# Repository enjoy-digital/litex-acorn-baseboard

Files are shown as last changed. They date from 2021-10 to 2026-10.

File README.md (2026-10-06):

                                  __   _ __      _  __    ___
                                 / /  (_) /____ | |/_/___/ _ |_______  _______
                                / /__/ / __/ -_)>  </___/ __ / __/ _ \/ __/ _ \
                               /____/_/\__/\__/_/|_|__ /_/ |_\__/\___/_/ /_//_/
                                 / _ )___ ____ ___ / /  ___  ___ ________/ /
                                / _  / _ `(_-</ -_) _ \/ _ \/ _ `/ __/ _  /
                               /____/\_,_/___/\__/_.__/\___/\_,_/_/  \_,_/
                                    Copyright 2021-2026 / Enjoy-Digital






[> Intro
--------

The LiteX-Acorn-Baseboards are baseboards developed around the SQRL Acorn card (and the compatible
RHS Research LiteFury/NiteFury), extending their possibilities with additional connectivity and I/Os.
Two variants exist:

**Mini variant** — commercialized, available on our [webshop][webshop]:

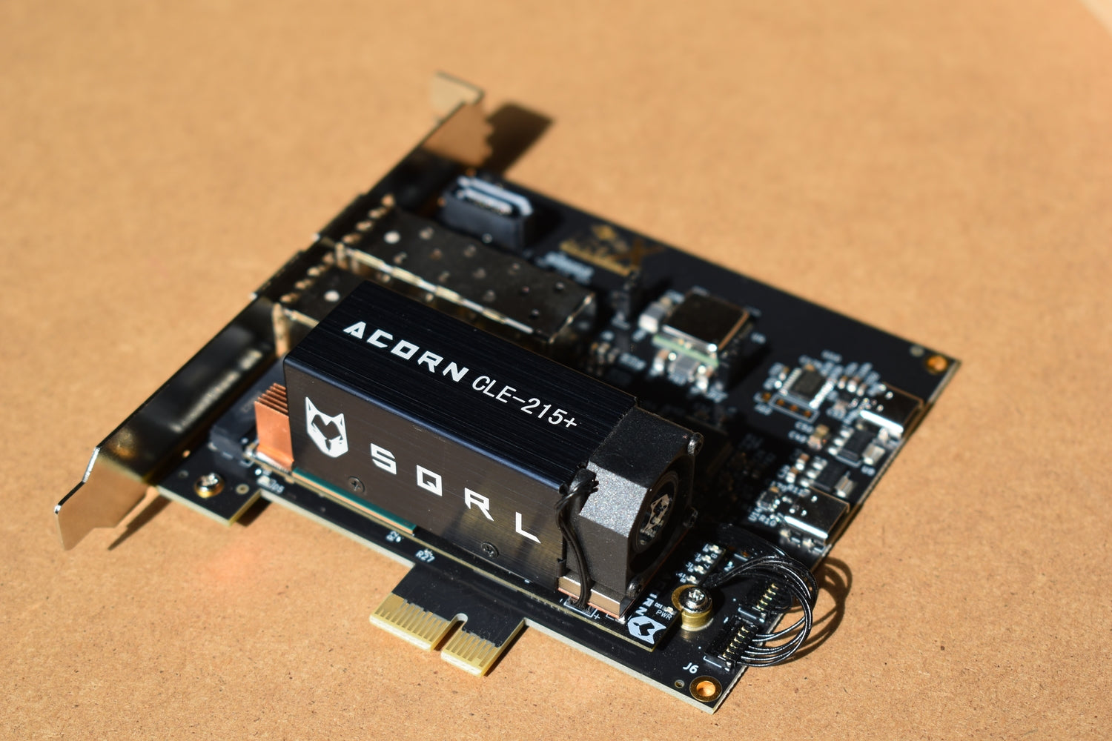
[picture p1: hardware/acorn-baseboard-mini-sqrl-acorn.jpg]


- An M.2 connector for the Acorn/LiteFury/NiteFury (or [LiteX-M2SDR][m2sdr]).
- A PCIe X1 connector.
- 2 SFP connectors.
- A SATA connector.
- 2 PicoEzMate connectors (GPIOs).
- 2 USB-C connectors: one for JTAG/UART (onboard FT2232H or FT4232H depending on the revision, auto-detected by the scripts) and one for power (onboard 3.3V regulator).

**Standard variant** — internal development only, not commercialized:

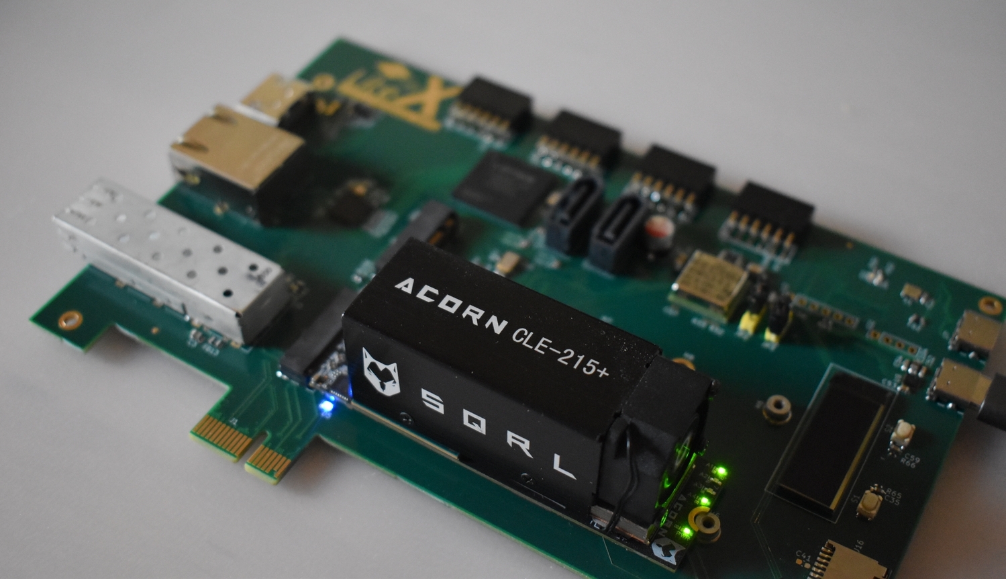
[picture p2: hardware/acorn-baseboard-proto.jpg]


- A PCIe X1 connector.
- An SFP connector.
- An M.2 SATA slot.
- An ECP5 FPGA (connected to the Acorn through a SerDes link) and providing:
  - A JTAG/UART port.
  - A 1Gbps Ethernet port (RGMII).
  - An HDMI Out port.
  - An SDCard slot.
  - 4 PMODs.
  - 2 Buttons.
  - An SSD1306 LCD.
  - 2 SATA connectors (connected to the ECP5's SerDeses).

The boards are primarily intended as development platforms for LiteX — from regression testing to
the development of new features — but they also make nice, affordable FPGA development boards for
anyone wanting to play with PCIe, SFP, SATA, etc., or to build standalone open-source Linux
platforms.

The development was specified and funded by [Enjoy-Digital][enjoy-digital] (@enjoy-digital), who
also did the HDL/gateware development. The schematic/PCB was designed by Ilia Sergachev
(@sergachev), who also assembled the initial prototypes.

[> Availability & Pricing
-------------------------

The **Mini variant** is produced in small batches and available on our webshop:

- Baseboard alone: https://enjoy-digital-shop.myshopify.com/products/litex-acorn-baseboard-mini
- Baseboard + SQRL Acorn CLE215 bundle:
  https://enjoy-digital-shop.myshopify.com/products/litex-acorn-baseboard-mini-sqrl-acorn-cle215

The **Standard variant** is currently used for internal R&D; no decision has been made yet about
producing it commercially.

The aim of the boards is to enable new kinds of designs with LiteX and to make it easier for users
to experiment with the framework and eventually contribute. **We produce and sell them to help
others have fun with LiteX/SerDes-based cores more than to make a living**, so batches are of
limited size and still partly assembled by hand. We try to stay responsive, but **there can be a
delay between batches (~1 month) and a few days between order and shipment**.

[> Getting Started
------------------

### Prerequisites
- Python 3.
- Xilinx Vivado (for the Acorn's Artix-7 FPGA).
- OpenOCD **0.12+** — [`flash.py --unprotect`](flash.py) uses `jtagspi cmd`, which is
  missing in 0.11. Set `OPENOCD=/path/to/openocd` to override the system binary.
- [openFPGALoader](https://github.com/trabucayre/openFPGALoader) — used by `flash.py --flash`.
- JTAG HS2 cable, or any OpenOCD-compatible cable (not needed for SPI-flash loading over PCIe).

### Installing LiteX
```bash
wget https://raw.githubusercontent.com/enjoy-digital/litex/master/litex_setup.py
chmod +x litex_setup.py
sudo ./litex_setup.py init install
```
... or follow the installation instructions from the LiteX Wiki:
https://github.com/enjoy-digital/litex/wiki/Installation

### First-time flashing (fresh Acorn card)
SQRL Acorn cards ship with their SPI flash in a factory-locked state — block-protect bits set
and, on many units, the Configuration Register QUAD bit set (flash stuck in QPI mode). In QPI
mode openFPGALoader's 1-wire SPI-over-JTAG stub can't even read the flash JEDEC ID, and the FPGA
fails to finish startup after loading the stub (`Done=0`). [`flash.py`](flash.py) splits the
job to work around both:
- `--unprotect` drives **OpenOCD** through a BSCAN-SPI proxy using `jtagspi cmd` to issue a
  software reset (0x66 → 0x99), `WRSR SR=0x00` to clear the block-protect bits, and
  `PPB_ERASE` for any non-volatile per-sector locks. CR is left untouched — `--flash` sets
  it below. SR/CR are read back before and after so you can see the state change.
- `--flash` uses **openFPGALoader** to erase + program the flash, then `--enable-quad` to set
  the flash's CR.QUAD bit to 1 — the Acorn boots in Master SPIx4 mode and needs QE=1 to fetch
  its bitstream on power-up. `--enable-quad` is idempotent, so running `--flash` again on an
  already-quad-enabled card is fine.

```bash
./flash.py --unprotect --flash                    # one-shot fresh-card bring-up
./flash.py --flash                                # re-flash default bitstream
./flash.py --flash --bitstream my_design.bin      # re-flash your own bitstream
./flash.py --unprotect                            # just unlock (no programming)
```
The default bitstream in [`prebuilt/`](prebuilt/) is the one we pre-load on boards shipped from the
webshop — a LiteX SoC with PCIe / Ethernet / SATA support, useful as a sanity check that the board
is alive before flashing your own design.

### First build (Mini variant)
A good starting point is the LiteX-Boards target, which covers SoC / DRAM / PCIe / Ethernet / SATA:
```bash
cd litex-boards/litex_boards/targets/
./litex_acorn_baseboard_mini.py --with-pcie --build --load
```
At this stage, if everything works correctly, you should see "LED Phaser" (chaser/wave) animation across LEDs A1 through A4.

See [Designs & Apps](#-designs--apps) below for more involved examples (Linux, PTP, SerDes…).

[> Repository Layout
--------------------

### Schematics — [`hardware/`](hardware/)
- [`acorn-baseboard-mini-2022-06-06.pdf`](hardware/acorn-baseboard-mini-2022-06-06.pdf) — Mini
  variant schematic.
- [`README.md`](hardware/README.md) — Mini variant connectors/jumpers reference (pinouts, power
  and SFP I2C jumpers settings).
- [`acorn-baseboard-mini-top.png`](hardware/acorn-baseboard-mini-top.png) — Mini variant PCB top
  render (connectors/jumpers references).
- [`acorn-baseboard-mini-3d.png`](hardware/acorn-baseboard-mini-3d.png) — Mini variant 3D view.
- [`acorn-baseboard-mini.step`](hardware/acorn-baseboard-mini.step) — Mini variant 3D model (STEP,
  generated from KiCad; U4 RECOM DC/DC and U9 FUSB302 are simplified models).
- [`acorn-baseboard-2021-07-02.pdf`](hardware/acorn-baseboard-2021-07-02.pdf) — Standard variant
  schematic.
- [`acorn.pdf`](hardware/acorn.pdf) — SQRL Acorn card schematic (for reference).

### Bring-up tests — [`bringup/`](bringup/)
Small, self-contained LiteX designs used to validate each sub-system. They are a good source of
minimal examples when you want to reproduce only one feature.

**Mini variant** — [`bringup/mini/`](bringup/mini/):
- [`acorn_litex_soc/`](bringup/mini/acorn_litex_soc/) — Minimal LiteX SoC (BIOS over JTAG-UART).
- [`acorn_pcie/`](bringup/mini/acorn_pcie/) — PCIe Gen2 X1 bring-up.
- [`acorn_serdes/`](bringup/mini/acorn_serdes/) — SerDes PRBS/BER test (PCIe and SFP loopback).
- [`acorn_sfp_eth_1000basex/`](bringup/mini/acorn_sfp_eth_1000basex/) — 1000BASE-X Ethernet over SFP.
- [`acorn_sfp_eth_2500basex/`](bringup/mini/acorn_sfp_eth_2500basex/) — 2500BASE-X Ethernet over SFP.

**Standard variant** — [`bringup/standard/`](bringup/standard/):
- [`acorn_pcie/`](bringup/standard/acorn_pcie/), [`acorn_sata/`](bringup/standard/acorn_sata/),
  [`acorn_sfp_eth_1gbps/`](bringup/standard/acorn_sfp_eth_1gbps/) — Acorn-side peripherals.
- [`acorn_ecp5_link/`](bringup/standard/acorn_ecp5_link/),
  [`acorn_i2c_ecp5/`](bringup/standard/acorn_i2c_ecp5/) — Acorn ↔ ECP5 link and I²C boot control.
- [`ecp5_eth_1gbps/`](bringup/standard/ecp5_eth_1gbps/),
  [`ecp5_hdmi_out/`](bringup/standard/ecp5_hdmi_out/),
  [`ecp5_lcd/`](bringup/standard/ecp5_lcd/),
  [`ecp5_sdcard/`](bringup/standard/ecp5_sdcard/) — ECP5-side peripherals.

[> Designs & Apps
-----------------

The Mini variant is supported across the LiteX ecosystem; good entry points include:

- **LiteX-Boards** — reference SoC target with SoC / DRAM / PCIe / Ethernet / SATA support:
  https://github.com/litex-hub/litex-boards/blob/master/litex_boards/targets/litex_acorn_baseboard_mini.py
- **Linux-on-LiteX-VexRiscv** — run Linux on a VexRiscv SoC (`--board=acorn_baseboard_mini`):
  https://github.com/litex-hub/linux-on-litex-vexriscv
- **LiteX-HW-CI** — Linux regression tests on the board with VexRiscv, NaxRiscv (32/64-bit) or Rocket:
  https://github.com/enjoy-digital/litex_hw_ci/blob/main/configs/test_linux_acorn.py
- **LiteEth** — PTP bench on the board:
  https://github.com/enjoy-digital/liteeth/blob/master/bench/acorn_baseboard_mini_ptp.py
- **LiteICLink** — SerDes PRBS/BER bench on the SQRL Acorn (usable standalone or through the Mini):
  https://github.com/enjoy-digital/liteiclink/blob/master/bench/serdes/sqrl_acorn.py
- **LitePCIe** — PCIe bench on the SQRL Acorn:
  https://github.com/enjoy-digital/litepcie/blob/master/bench/acorn.py
- **LiteSATA** — SATA bench on the SQRL Acorn:
  https://github.com/enjoy-digital/litesata/blob/master/bench/acorn.py

... and more to come. :)

[> Validation Status
--------------------

**Mini variant:**
- [x] PCIe Gen2 X1.
- [x] JTAG.
- [x] UART.
- [x] SFPs.
- [x] SATA.

**Standard variant:**
- [x] PCIe Gen2 X1.
- [x] SFP.
- [x] M.2 SATA SSD.
- [x] ECP5 JTAG/UART.
- [x] Acorn JTAG.
- [ ] Acorn/ECP5 Fast Link.
- [x] Acorn/ECP5 Slow Link (2 of 4 lanes tested).
- [x] ECP5 boot control from Acorn via I²C.
- [x] 1Gbps Ethernet.
- [x] HDMI Out.
- [x] SDCard.
- [x] 4× PMODs.
- [x] 2× Buttons.
- [x] SSD1306 LCD.
- [ ] 2× ECP5 SATA.

[> Contact
----------
E-mail: florent@enjoy-digital.fr

[webshop]: https://enjoy-digital-shop.myshopify.com/
[enjoy-digital]: https://enjoy-digital.fr
[m2sdr]: https://github.com/enjoy-digital/litex_m2sdr

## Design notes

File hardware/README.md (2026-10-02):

[> LiteX-Acorn-Baseboard-Mini: Connectors & Jumpers
---------------------------------------------------

Connectors/jumpers reference for the Mini variant, extracted from the
[schematic](acorn-baseboard-mini-2022-06-06.pdf). See the [top render](acorn-baseboard-mini-top.png)
to locate the references on the PCB (positions below are given with the PCIe edge connector at the
bottom, as in the render).

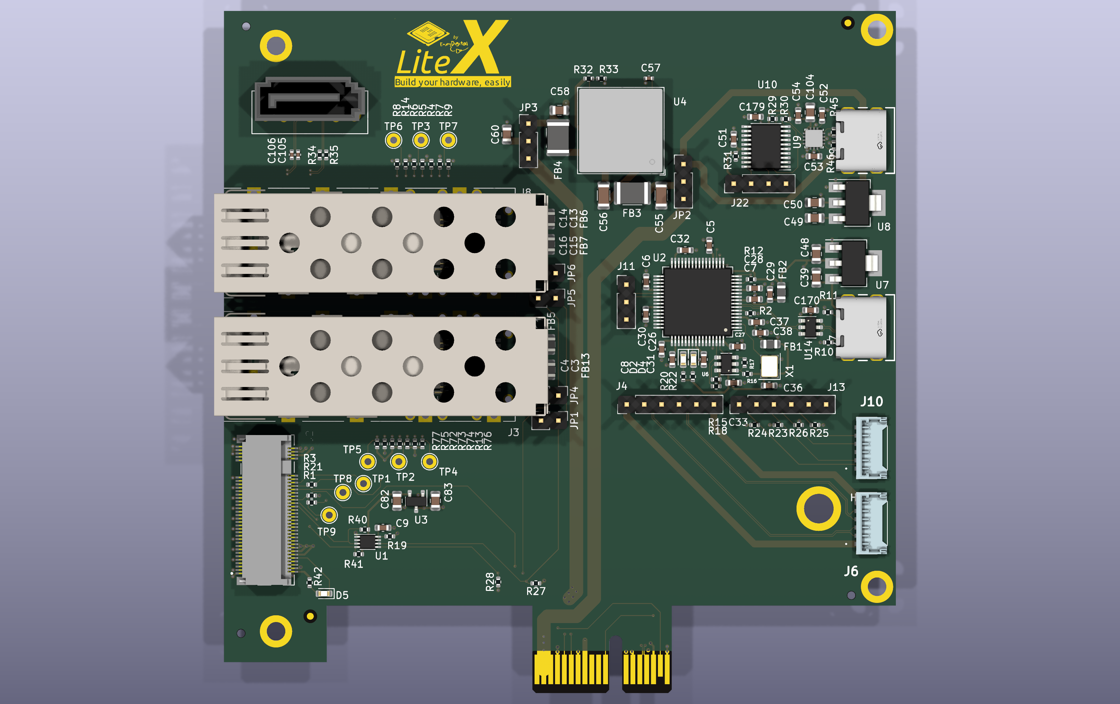
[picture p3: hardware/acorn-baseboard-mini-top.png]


[> Connectors
-------------

| Ref | Description | Notes |
|-----|---|---|
| J1  | PCIe X1 Gen2 card edge. | Also provides +12V/+3.3V power (see JP2/JP3) and SMBus (see JP1/JP4/JP5/JP6). |
| J2  | M.2 key M socket. | For the SQRL Acorn / LiteFury / NiteFury (or LiteX-M2SDR). |
| J3  | SFP0 cage (bottom one, closest to the M.2).  | `sfp0` in the gateware. |
| J8  | SFP1 cage (top one, closest to the SATA). | `sfp1` in the gateware. |
| J5  | SATA connector. | |
| J7  | USB-C (bottom one): JTAG/UART. | Onboard FTDI chip (FT2232H/FT4232H depending on the revision). Also powers the FTDI chip. |
| J9  | USB-C (top one): Power input. | USB Power-Delivery (FUSB302 + STM32 U10). Main power input when not in a PCIe slot. |
| J10 | Pico-EZmate 6-pin: Acorn JTAG. | Connect to the Acorn JTAG connector with a Pico-EZmate 6 cable. |
| J6  | Pico-EZmate 6-pin: Acorn I/O (P2). | Connect to the Acorn P2 connector with a Pico-EZmate 6 cable. |
| J4  | 2.54mm 6-pin header: Acorn I/O breakout. | Same signals as J6 (pin to pin). |
| J13 | 2.54mm 6-pin header: External JTAG. | Shared with the onboard FTDI JTAG and J10, for an external JTAG cable (ex Digilent HS2). |
| J11 | 2.54mm 3-pin header: FTDI UART. | UART also routed to the Acorn through the M.2 connector (no wiring needed). |
| J22 | 2.54mm 4-pin header: STM32 (U10) SWD. | USB-PD controller programming. |

### Pinouts

**J13 — External JTAG** (pin 6 = VDD, compatible with the Digilent HS2 pin order):

| Pin | 1 | 2 | 3 | 4 | 5 | 6 |
|-----|-----|-----|-----|-----|-----|---|
| | TMS | TDI | TDO | TCK | GND | +3V3 |

**J10 — Acorn JTAG (Pico-EZmate)**:

| Pin | 1  | 2 | 3 | 4 | 5 | 6 |
|-----|----|-----|-----|-----|-----|-----|
| | NC | TDI | TMS | TDO | TCK | GND |

**J4/J6 — Acorn I/O (P2)**:

| Pin | 1 | 2 | 3 | 4 | 5 | 6 |
|-----|---|---|---|---|---|---|
| | Acorn P2.1 | AIO1N | AIO1P | AIO2N | AIO2P | Acorn P2.6 |

**J11 — FTDI UART** (FTDI channel B, LiteX `serial` on the Acorn):

| Pin | 1 | 2 | 3 |
|-----|---|---|-----|
| | FTDI TX (-> FPGA RX) | FTDI RX (<- FPGA TX) | GND |

The UART is routed to the Acorn through the M.2 connector (FTDI TX -> M.2 SMB_ALERT#, M.2
CLKREQ# -> FTDI RX) so J11 is only needed to monitor or connect to the UART externally.

**J22 — STM32 SWD**:

| Pin | 1 | 2 | 3 | 4 |
|-----|---|---|---|-----|
| | +3.3VA | SWCLK | SWDIO | GND |

[> Jumpers
----------

| Ref | Function | Setting |
|-----|---|---|
| JP2 | 1st power input selector: DC/DC (U4) input. | 1-2: from USB-C J9 (VBUS). 2-3: from PCIe edge connector (+12V). |
| JP3 | 2nd power input selector: Baseboard +3V3 rail. | 1-2: from onboard 3.3V DC/DC (U4, also powering the M.2/Acorn). 2-3: from PCIe edge connector (+3.3V). |
| JP1 | SFP0 I2C SCL <-> PCIe/M.2 SMBus SCL. | Close to access SFP0 I2C (module EEPROM/DDM). |
| JP4 | SFP0 I2C SDA <-> PCIe/M.2 SMBus SDA. | Close to access SFP0 I2C (module EEPROM/DDM). |
| JP5 | SFP1 I2C SCL <-> PCIe/M.2 SMBus SCL. | Close to access SFP1 I2C (module EEPROM/DDM). |
| JP6 | SFP1 I2C SDA <-> PCIe/M.2 SMBus SDA. | Close to access SFP1 I2C (module EEPROM/DDM). |

Notes:
- The Acorn (M.2) is always powered from the onboard 3.3V DC/DC (U4), so JP2 has to be set in all
  cases: 1-2 when powered from USB-C J9 (standalone), 2-3 to use the PCIe +12V when in a PCIe slot.
- The SFP I2C buses are connected to the PCIe SMBus and, through a PCA9306 level-shifter (U1), to
  the M.2 SMBus (`sfp_i2c` in the gateware). Since SFP modules all use the same I2C addresses
  (0x50/0x51), only close the jumpers of one SFP at a time (JP1+JP4 for SFP0 or JP5+JP6 for SFP1).

[> Known Issues
---------------

**SFP TX_DISABLE pull-downs too weak** ([#22](https://github.com/enjoy-digital/litex-acorn-baseboard/issues/22)):
TX_DISABLE (SFP pin 3) is only pulled down to GND by a 4.7k resistor (R75 for SFP0/J3, R7 for
SFP1/J8). SFF-8431 modules have an internal 4.7k-10k pull-up on TX_DISABLE, so with some modules
(mostly copper modules with an internal PHY) TX_DISABLE sits around 1.65V, between the logic
levels, and the module behaves erratically. Replacing R75/R7 with a 1k resistor (or lower) keeps
TX_DISABLE below 0.8V and fixes it.

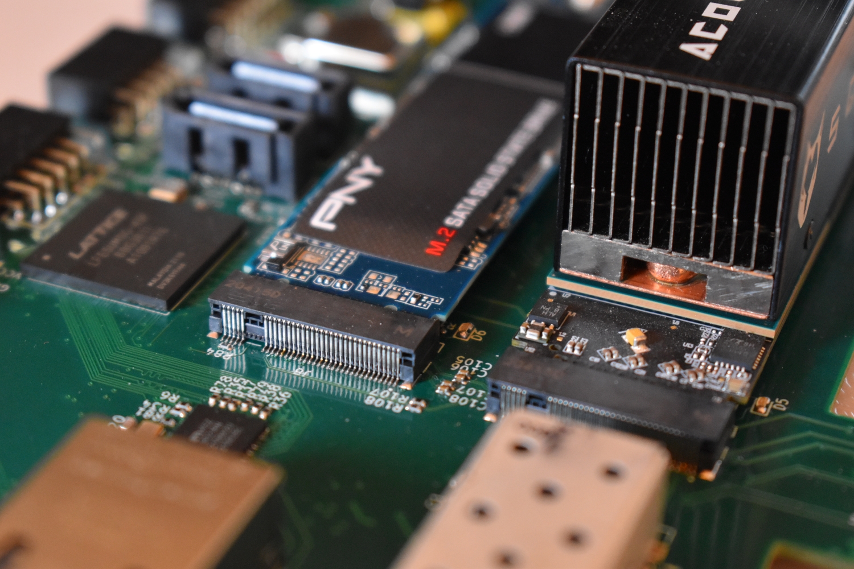
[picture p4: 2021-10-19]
hardware/acorn-baseboard-m2-ssd.jpg

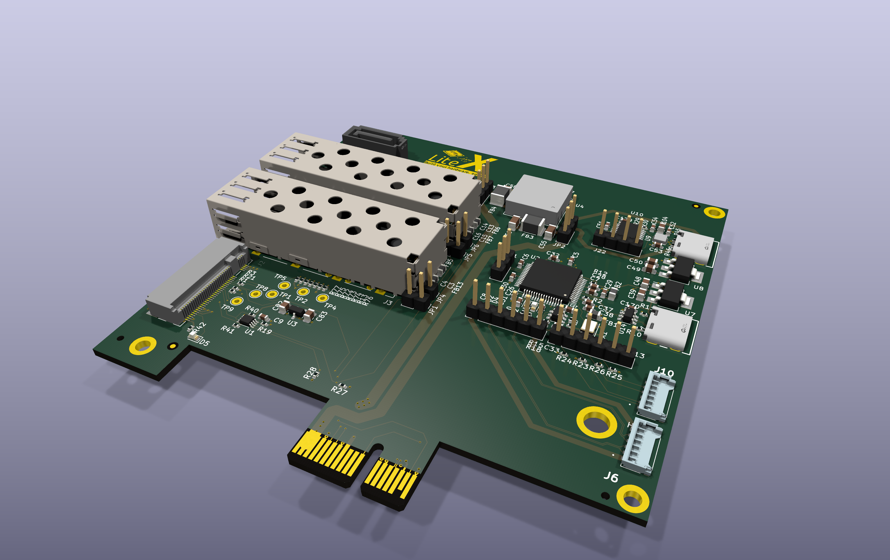
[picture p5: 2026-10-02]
hardware/acorn-baseboard-mini-3d.png

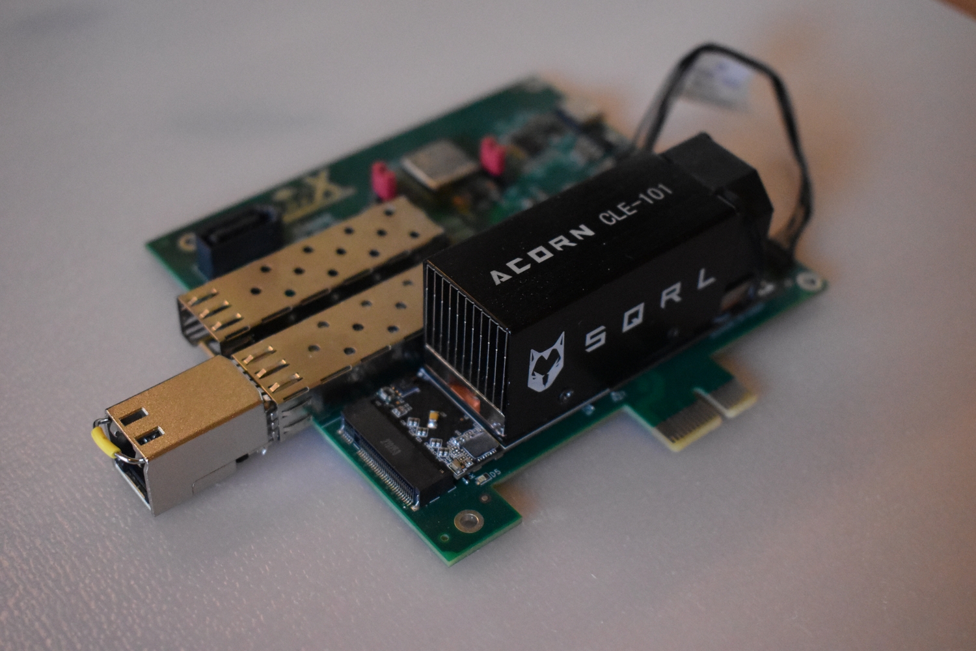
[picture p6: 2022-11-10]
hardware/acorn-baseboard-mini-proto.jpg

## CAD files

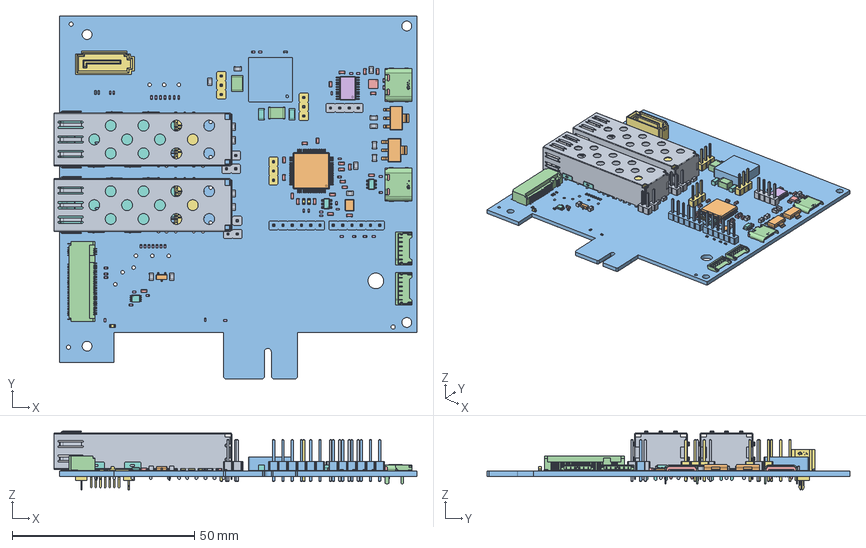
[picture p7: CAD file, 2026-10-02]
hardware/acorn-baseboard-mini.step
99.4 x 99.5 x 16.1 mm
CONN-SMD_APCI0107-P001A
CONN-SMD_20P-P0.80_HCTL_HC-SFP-20P x 2
TH_HC-SFP-01L x 2
LQFP-64_10x10mm_P0.5mm
RECOM_RPM3.3-6.0
C_0603_1608Metric x 26
R_0402_1005Metric x 46
LED_0603_1608Metric x 3
SOT-23-6 x 2
C_0805_2012Metric x 13
SOT-223 x 2
C_0402_1005Metric x 3
L_1812_4532Metric x 2
WQFN-14_2.5x2.5mm
TSSOP-20_4.4x6.5mm_P0.65mm
PinHeader_1x03_P2.54mm_Vertical x 3
C_1206_3216Metric x 2
L_0805_2012Metric x 6
PinHeader_1x04_P2.54mm_Vertical
Crystal_SMD_3225-4Pin_3.2x2.5mm
PinHeader_1x06_P2.54mm_Vertical x 2
USB-C-SMD_TYPEC-304J-BCP16 x 2
CONN-TH_HYC_HYCW01-SATA07-205B
VSSOP-8_2.3x2mm_P0.5mm
PinHeader_1x02_P2.54mm_Vertical x 4
SOT-23
patched_PCB

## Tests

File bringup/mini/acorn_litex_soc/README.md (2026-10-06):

[> Setup
--------
- Power from USB-C (J9).
- USB-C/JTAG connected to Host (J7).
- J10 to Acorn's JTAG connected through PICOEZMATE 6 cable.

[> Build
--------
- ./sqrl_acorn.py --build --load
- litex_term /dev/ttyUSBX (X=2 if only the baseboard connected).

[> Check
--------
LiteX BIOS showing up in litex_term.

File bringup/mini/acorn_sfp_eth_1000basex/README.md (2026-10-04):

[> Setup
--------
- Power from USB-C (J9).
- USB-C/JTAG connected to Host (J7).
- J10 to Acorn's JTAG connected through PICOEZMATE 6 cable.
- SFP 1000-Base-X <-> RJ45 module in SFP0.
- SFP 1000-Base-X <-> RJ45 module in SFP1.

[> Build
--------
./sqrl_acorn.py --build --load

[> Check
--------
- ping 192.168.1.50 responding on SFP0.
- ping 192.168.1.51 responding on SPF1.

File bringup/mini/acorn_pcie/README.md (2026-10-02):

[> Setup
--------
- Power from USB-C (J9).
- USB-C/JTAG connected to Host (J7).
- J10 to Acorn's JTAG connected through PICOEZMATE 6 cable.
- Board in PCIe slot.

[> Build
--------
./sqrl_acorn.py --with-pcie --build --load

Or, to keep the bitstream across power cycles, flash it to the SPI flash:

./sqrl_acorn.py --with-pcie --build --flash

[> Check
--------
Board seen with lspci (Xilinx vendor ID 10ee, device ID 7021 for X1):

lspci -d 10ee:

The first Acorn LED is a LED chaser (bitstream loaded), the second one reflects the PCIe link status.

Note: the host only enumerates PCIe devices at boot, so a bitstream loaded while the host is
running will not appear directly in lspci. The host has to re-enumerate the bus:
- With --load: do a warm reboot of the host. Since the baseboard is powered from its own USB-C
  (J9), the FPGA keeps its configuration across the reboot.
- With --flash: power-cycle the board (or the host) so the FPGA boots from the SPI flash, then
  boot the host.
- A PCIe rescan without reboot (sudo sh -c "echo 1 > /sys/bus/pci/rescan") may also work on some
  hosts, but is not reliable: a reboot is the recommended method.

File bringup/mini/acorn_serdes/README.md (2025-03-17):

[> Setup
--------
- Power from USB-C (J9).
- USB-C/JTAG connected to Host (J7).
- J10 to Acorn's JTAG connected through PICOEZMATE 6 cable.
- PCIe loopback board.
- SFP loopback module.

[> Build
--------
./sqrl_acorn.py --connector=pcie --build --load

[> Check
--------
litex_server --uart --uart-port=/dev/ttyUSBX (X=2 if only the baseboard connected).
./test_prbs.py:
Creating Serdes0
Measuring Serdes0 frequencies...
TX freq:    126.362MHz
RX freq:    126.362MHz
Configuring Serdes0...
Setting PRBS to PRBS7 mode.
Running PRBS/BER test...
Errors:          2 / Duration:  0.50s / BER: 0.000e+00
Errors:          0 / Duration:  1.00s / BER: 0.000e+00
Errors:          0 / Duration:  1.50s / BER: 0.000e+00
Errors:          0 / Duration:  2.00s / BER: 0.000e+00
Errors:          0 / Duration:  2.50s / BER: 0.000e+00
Errors:          0 / Duration:  3.00s / BER: 0.000e+00
Errors:          0 / Duration:  3.50s / BER: 0.000e+00
Errors:          0 / Duration:  4.00s / BER: 0.000e+00
Errors:          0 / Duration:  4.50s / BER: 0.000e+00

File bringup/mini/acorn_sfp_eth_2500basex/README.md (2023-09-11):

[> Setup
--------
- Power from USB-C (J9).
- USB-C/JTAG connected to Host (J7).
- J10 to Acorn's JTAG connected through PICOEZMATE 6 cable.
- SFP 2500-Base-X <-> RJ45 module in SFP0.

[> Build
--------
./sqrl_acorn.py --build --load

[> Check
--------
ping 192.168.1.50 responding.

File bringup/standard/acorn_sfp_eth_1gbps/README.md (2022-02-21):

[> Setup
--------
- Power from USB-C (J9).
- JTAG HS2 to Acorn.
- SFP 1000-BaseX Module (J3).

[> Build
--------
./sqrl_acorn.py --build --load

[> Check
--------
Verify that the board can be pinged at 192.168.1.50.

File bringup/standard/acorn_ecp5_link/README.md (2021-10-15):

[> Setup
--------
- Power from USB-C (J9).
- JTAG HS2 to Acorn.

[> Build
--------
./sqrl_acorn.py --connector=sfp --build --load

[> Check
--------
TODO.

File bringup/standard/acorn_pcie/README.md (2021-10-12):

[> Setup
--------
- Power from USB-C (J9).
- JTAG HS2 to Acorn.
- Board in PCIe slot (J1).

[> Build
--------
./sqrl_acorn.py --with-pcie --build --load

[> Check
--------
Board seen with lspci.

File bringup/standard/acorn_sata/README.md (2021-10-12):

[> Setup
--------
- Power from USB-C (J9).
- JTAG from USB-C (J7).
- JTAG HS2 to Acorn.
- SATA M2 SSD (J8).

[> Build
--------
python3 acorn.py --gen=1 --with-analyzer --build --load
python3 -m litex_boards.targets.litex_acorn_baseboard --cpu-type=None --build --load

[> Check
--------
./test_init.py

    Success (retries: 0)

./test_bist.py -i

    Serial Number: PNY21242106160100189
    Firmware Revision: CS900BB3
    Model Number: PNY CS900 M.2 250GB SSD
    Capacity: 232.89 GiB
    SATA Gen1: 1
    SATA Gen2: 1
    SATA Gen3: 1
    48 bits LBA supported: 1

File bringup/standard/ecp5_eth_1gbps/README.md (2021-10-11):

[> Setup
--------
- Power from USB-C (J9).
- JTAG from USB-C (J7).

[> Build
--------
python3 -m litex_boards.targets.litex_acorn_baseboard --with-etherbone --build --load

[> Check
--------
Verify that the board can be pinged at 192.168.1.50.

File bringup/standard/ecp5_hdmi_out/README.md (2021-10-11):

[> Setup
--------
- Power from USB-C (J9).
- JTAG from USB-C (J7).
- HDMI monitor connected to HDMI Out (J14).

[> Build
--------
python3 -m litex_boards.targets.litex_acorn_baseboard --with-video-terminal --build --load

[> Check
--------
Verify that LiteX BIOS prompt is displayed on the HDMI monitor.

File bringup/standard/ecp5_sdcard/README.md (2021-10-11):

[> Setup
--------
- Power from USB-C (J9).
- JTAG from USB-C (J7).
- SDCard.

[> Build
--------
python3 -m litex_boards.targets.litex_acorn_baseboard --integrated-main-ram-size=0x1000 --with-sdcard --build --load

[> Check
--------

litex_term /dev/ttyUSBX

Without SDCard in slot:

    litex> sdcard_init
    Initialize SDCard... Failed.

With SDCard in slot:

    litex> sdcard_init
    Initialize SDCard... Successful.

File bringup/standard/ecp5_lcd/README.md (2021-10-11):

[> Setup
--------
- Power from USB-C (J9).
- JTAG from USB-C (J7).

[> Build
--------
python3 -m litex_boards.targets.litex_acorn_baseboard --integrated-main-ram-size=0x2000 --with-lcd --build --load

[> Check
--------

litex_term /dev/ttyUSBX

    litex> i2c_scan
           0  1  2  3  4  5  6  7  8  9  a  b  c  d  e  f
    0x00: -- -- -- -- -- -- -- -- -- -- -- -- -- -- -- --
    0x10: -- -- -- -- -- -- -- -- -- -- -- -- -- -- -- --
    0x20: -- -- -- -- -- -- -- -- -- -- -- -- -- -- -- --
    0x30: -- -- -- -- -- -- -- -- -- -- -- -- 3c -- -- --
    0x40: -- -- -- -- -- -- -- -- -- -- -- -- -- -- -- --
    0x50: -- -- -- -- -- -- -- -- -- -- -- -- -- -- -- --
    0x60: -- -- -- -- -- -- -- -- -- -- -- -- -- -- -- --
    0x70: -- -- -- -- -- -- -- -- -- -- -- -- -- -- -- --

cd firmware && make
litex_term /dev/ttyUSBX --kernel=firmware.bin
lcd

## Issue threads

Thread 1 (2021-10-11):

Bringup: Validate Acorn / PCIe.

enjoy-digital, 2021-10-11:
Should work with:

`python3 -m litex_boards.targets.sqrl_acorn --with-pcie --build --load`

With link-width automatically reduced from X4 to X1.

enjoy-digital, 2024-04-19:
This has been validated on both Mini and Standard variants. Standard variants requires a TX/RX pairs swaps due to a schematic/hardware issue. Mini variant has this correction.

Closed 2024-04-19.

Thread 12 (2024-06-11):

Jumpers/connectors documentation and settings table

ohault, 2024-06-11:
Some documentation would be required for LiteX Acorn baseboard, both on PCB and on a wiki page.

Here is a first dump from the schematic.

**Mini variant**

Connectors
J4 : Acorn Pico-EZmate IO
J5 : SATA
J7 : USB Type C
J10 : Acorn JTAG
J11 : Conn_01x03 FT2232 RX/TX
J13 : JTAG header
J22 : STM32 SWD programming

Jumpers
JP2 : 1st power input selector
1-2 from USB-C
2-3 from PCIe edge connector

JP3: 2nd power input selector
1-2 from onboard 3V3 regulator
2-3 from PCIe edge connector

JP1 : SFP0_SCL
JP4 : SFP0_SDA

JP5 : SFP1_SCL
JP6 : SFP1_SDA

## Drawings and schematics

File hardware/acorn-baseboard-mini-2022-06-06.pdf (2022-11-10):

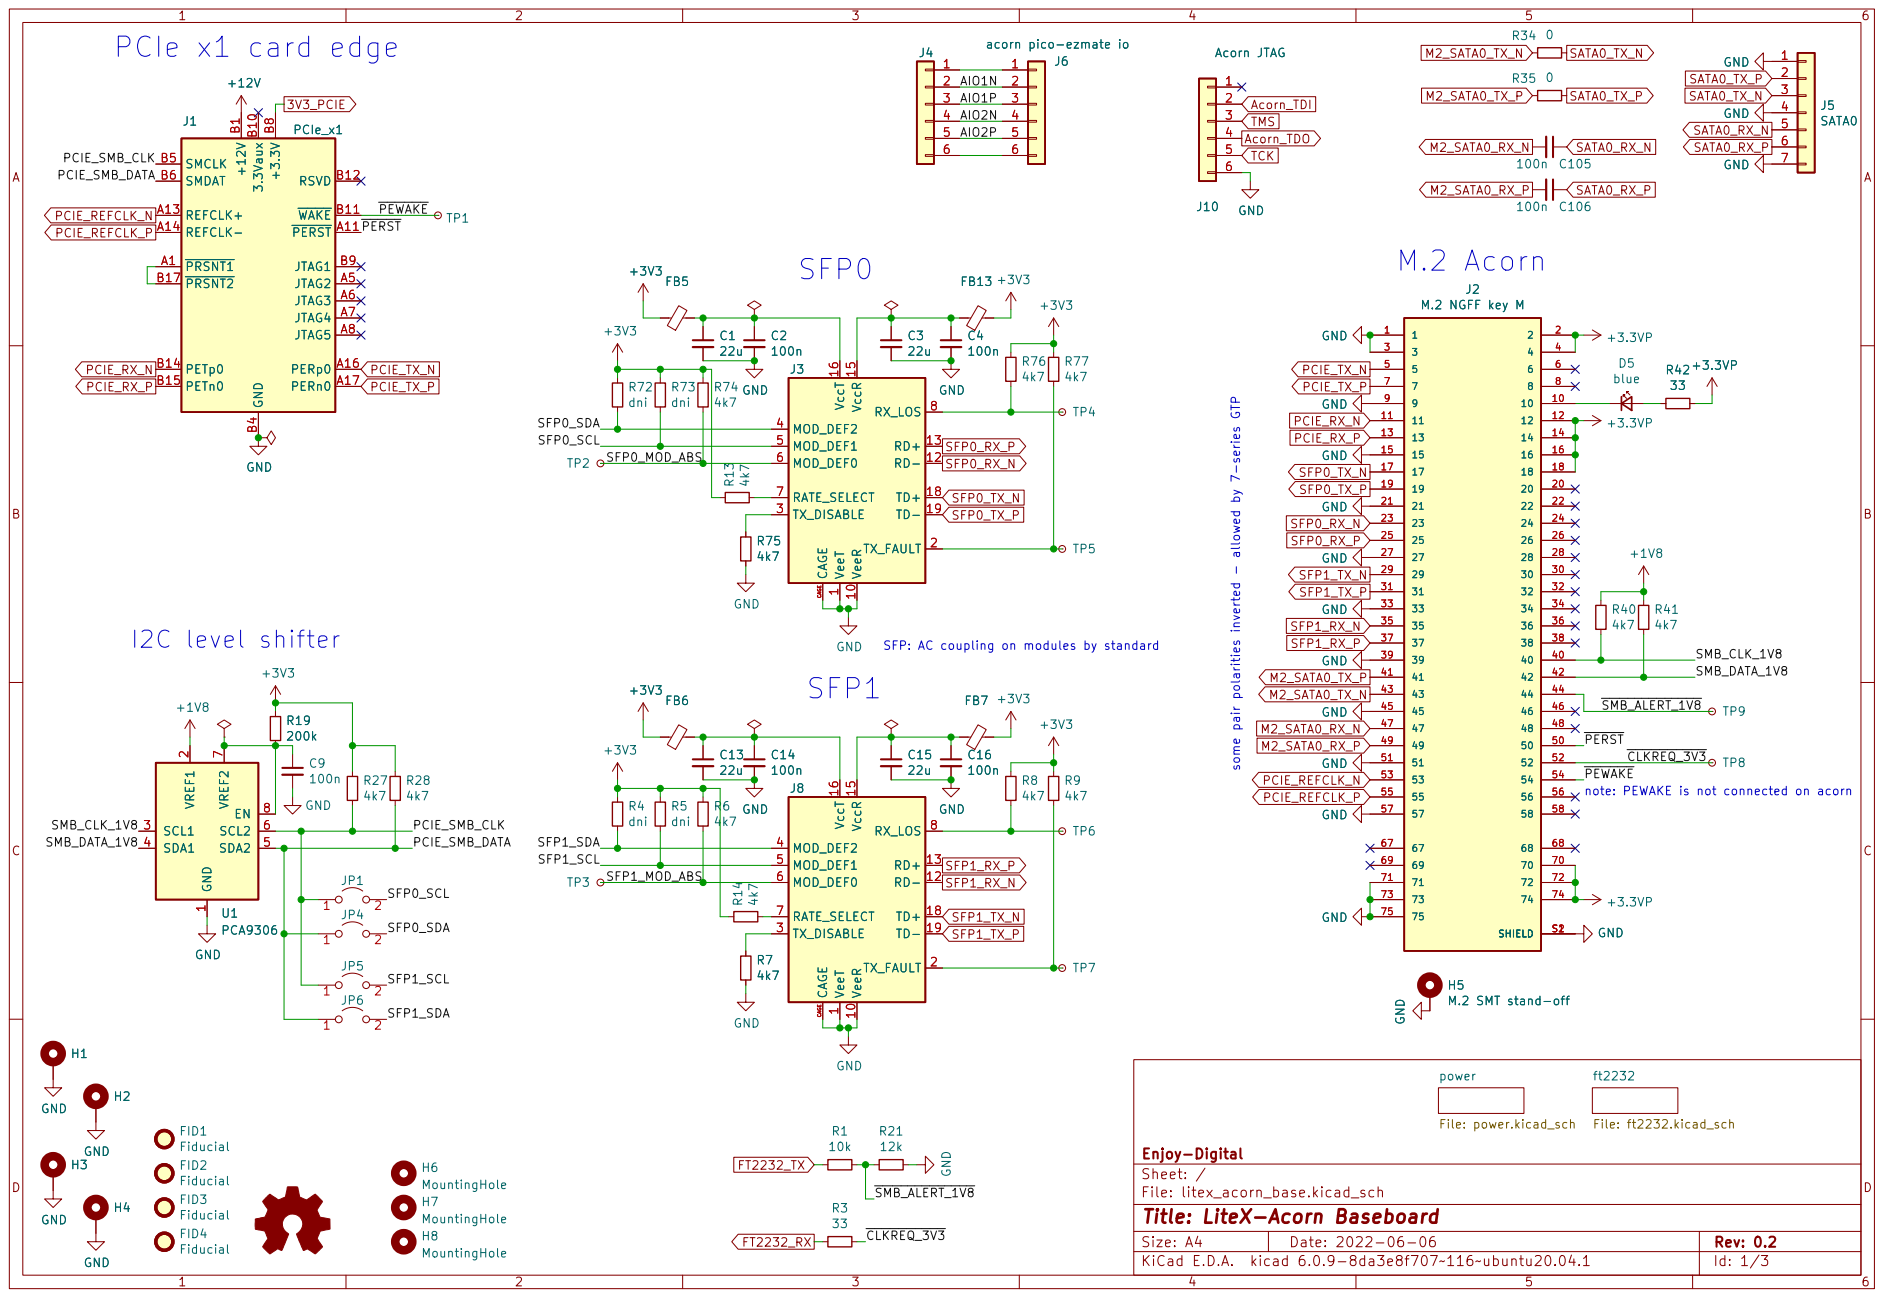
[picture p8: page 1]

acorn pico-ezmate io R9
J10Acorn JTAG

acorn pico-ezmate io

7 GND GND GND GND

note: PEWAKE is not connected on acorn M.2 Acorn

1 VeeR 10 RD- 12 RD+ 13 VccR 15 VccT 16 TD+ 18 TD- 19 TX_FAULT 2 TX_DISABLE 3 MOD_DEF2 4 MOD_DEF1 5 MOD_DEF0 6 RATE_SELECT 7 RX_LOS 8 CAGE CAGE J8 C2

1 VeeR 10 RD- 12 RD+ 13 VccR 15 VccT 16 TD+ 18 TD- 19 TX_FAULT 2 TX_DISABLE 3 MOD_DEF2 4 MOD_DEF1 5 MOD_DEF0 6 RATE_SELECT 7 RX_LOS 8 CAGE CAGE J3 GND GND GND
GND

1 VeeR 10 RD- 12 RD+ 13 VccR 15 VccT 16 TD+ 18 TD- 19 TX_FAULT 2 TX_DISABLE 3 MOD_DEF2 4 MOD_DEF1 5 MOD_DEF0 6 RATE_SELECT 7 RX_LOS 8 CAGE CAGE GND

power File: power.kicad_sch GND GND

1 VeeR 10 RD- 12 RD+ 13 VccR 15 VccT 16 TD+ 18 TD- 19 TX_FAULT 2 TX_DISABLE 3 MOD_DEF2 4 MOD_DEF1 5 MOD_DEF0 6 RATE_SELECT 7 RX_LOS 8 CAGE CAGE R7

H8MountingHole FID1 Fiducial FID3 Fiducial FID4 Fiducial FID2 Fiducial

File: litex_acorn_base.kicad_sch Sheet: / Enjoy-Digital

Id: 1/3 Title: LiteX-Acorn Baseboard

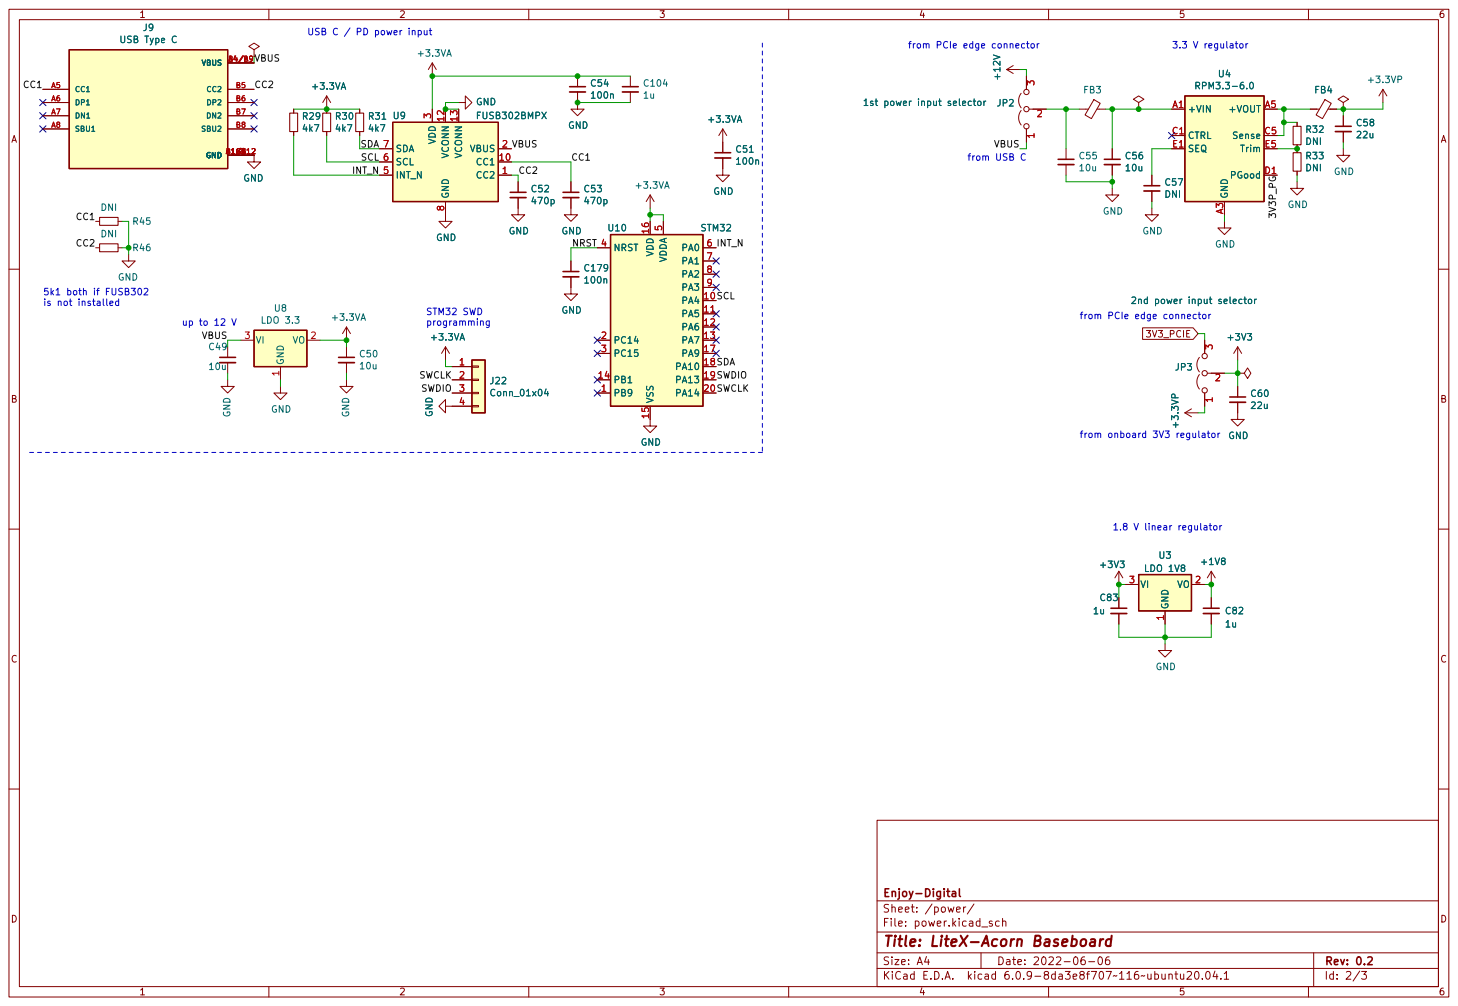
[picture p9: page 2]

USB C / PD power input

from PCIe edge connector

2nd power input selector +3V3 GND

Enjoy-Digital
Sheet: /power/
File: power.kicad_sch
Id: 2/3 Title: LiteX-Acorn Baseboard

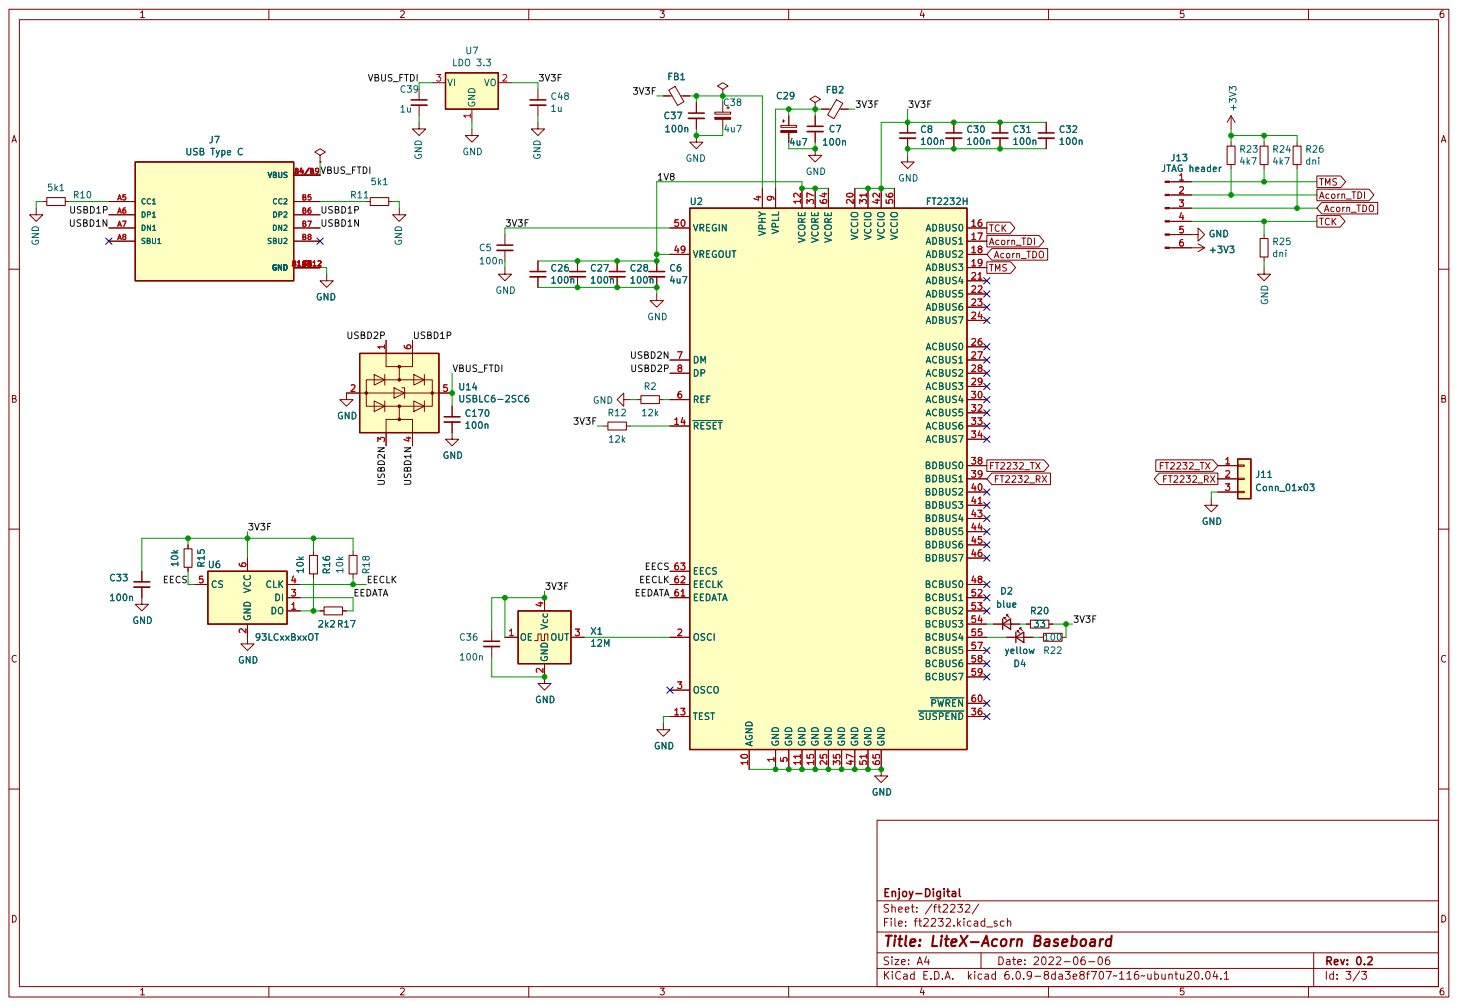
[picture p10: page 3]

1 AGND 10 GND 11 VCORE 12 TEST 13 ~{RESET} 14 GND 15 ADBUS0 16 ADBUS1 17 ADBUS2 18 ADBUS3 19 OSCI 2 VCCIO 20 ADBUS4 21 ADBUS5 22 ADBUS6 23 ADBUS7 24 GND 25 ACBUS0 26 ACBUS1 27 ACBUS2 28 ACBUS3 29 OSCO 3 ACBUS4 30 VCCIO 31 ACBUS5 32 ACBUS6 33 ACBUS7 34 GND 35

4 BDBUS2 40 BDBUS3 41 VCCIO 42 BDBUS4 43 BDBUS5 44 BDBUS6 45 BDBUS7 46 GND 47 BCBUS0 48 VREGOUT 49 GND

5 VREGIN 50 GND 51 BCBUS1 52 BCBUS2 53 BCBUS3 54 BCBUS4 55 VCCIO 56 BCBUS5 57 BCBUS6 58 BCBUS7 59 REF 6 ~{PWREN} 60 EEDATA 61 EECLK 62 EECS 63 VCORE 64 GND 65 DM 7 DP 8 VPLL

2 DI 3 CLK 4 CS 5 VCC

File: ft2232.kicad_sch Sheet: /ft2232/ Enjoy-Digital

Id: 3/3 Title: LiteX-Acorn Baseboard

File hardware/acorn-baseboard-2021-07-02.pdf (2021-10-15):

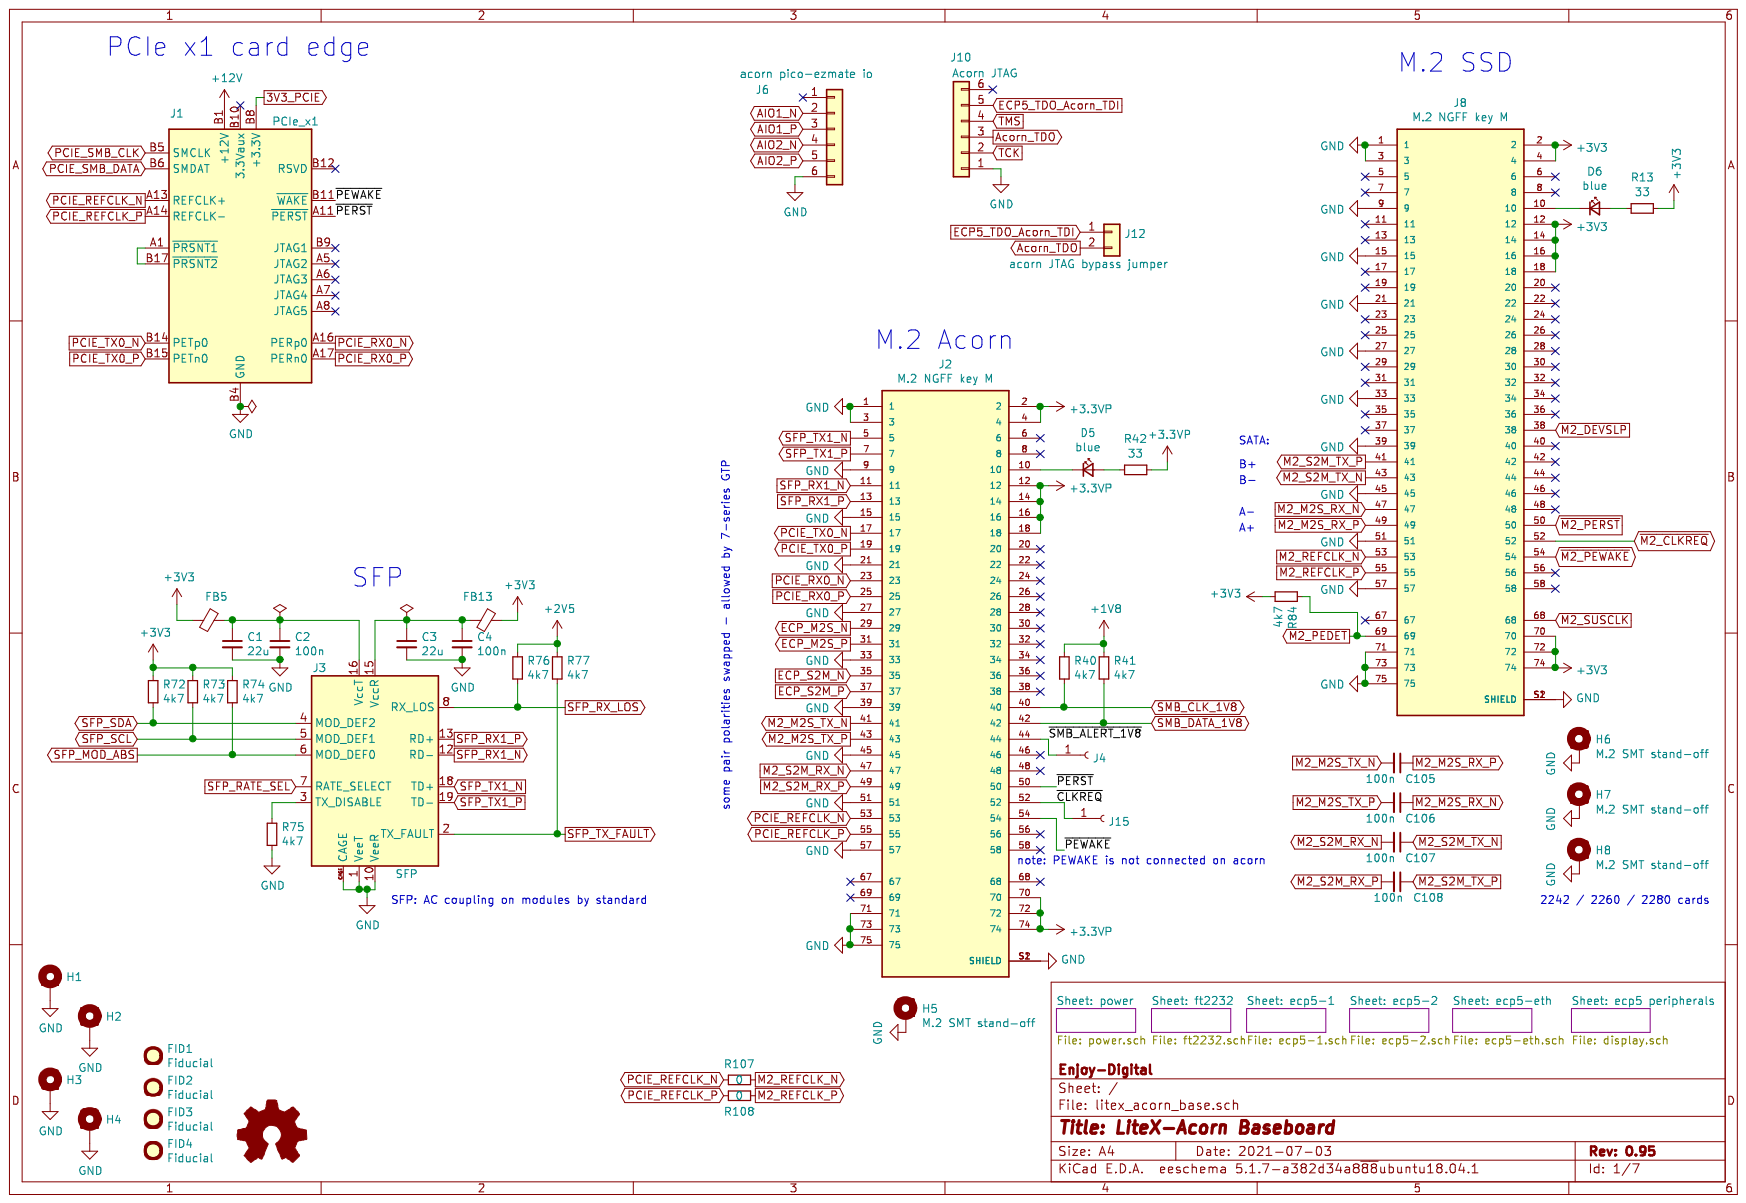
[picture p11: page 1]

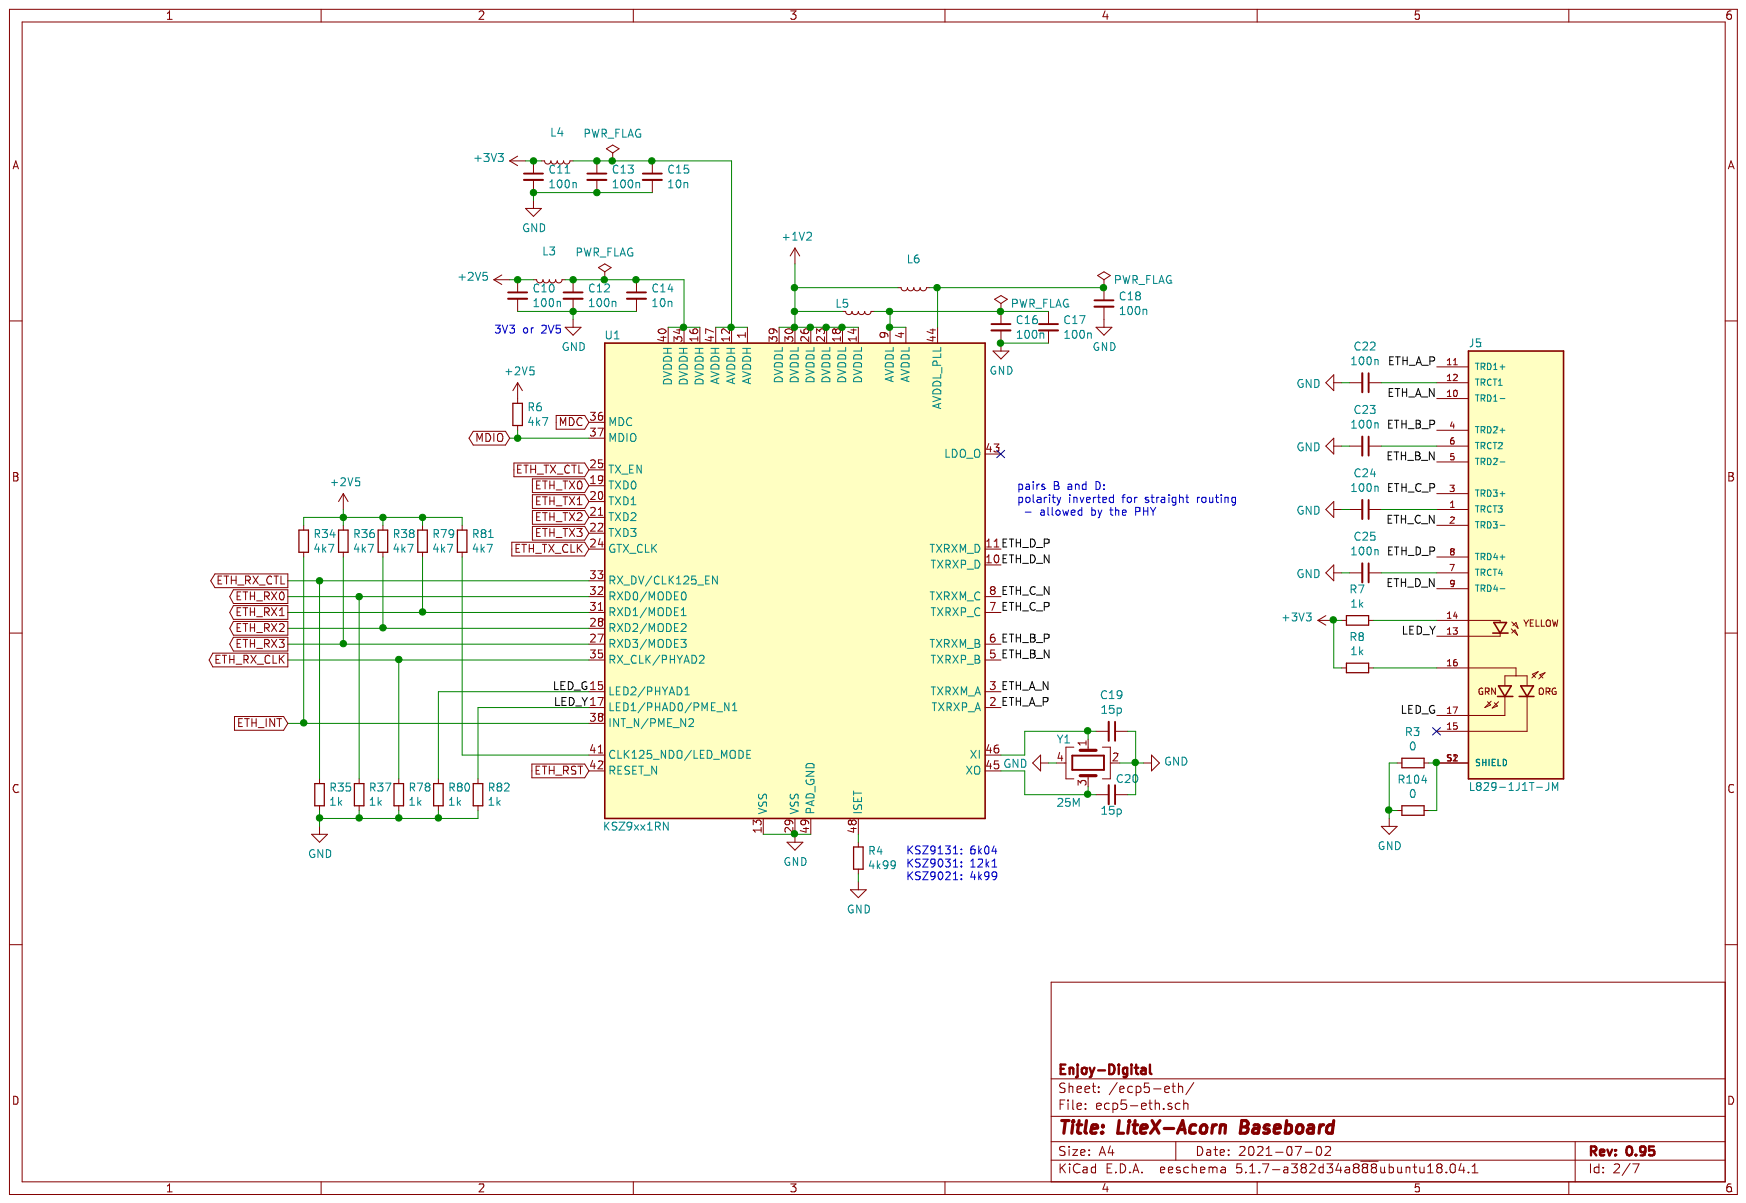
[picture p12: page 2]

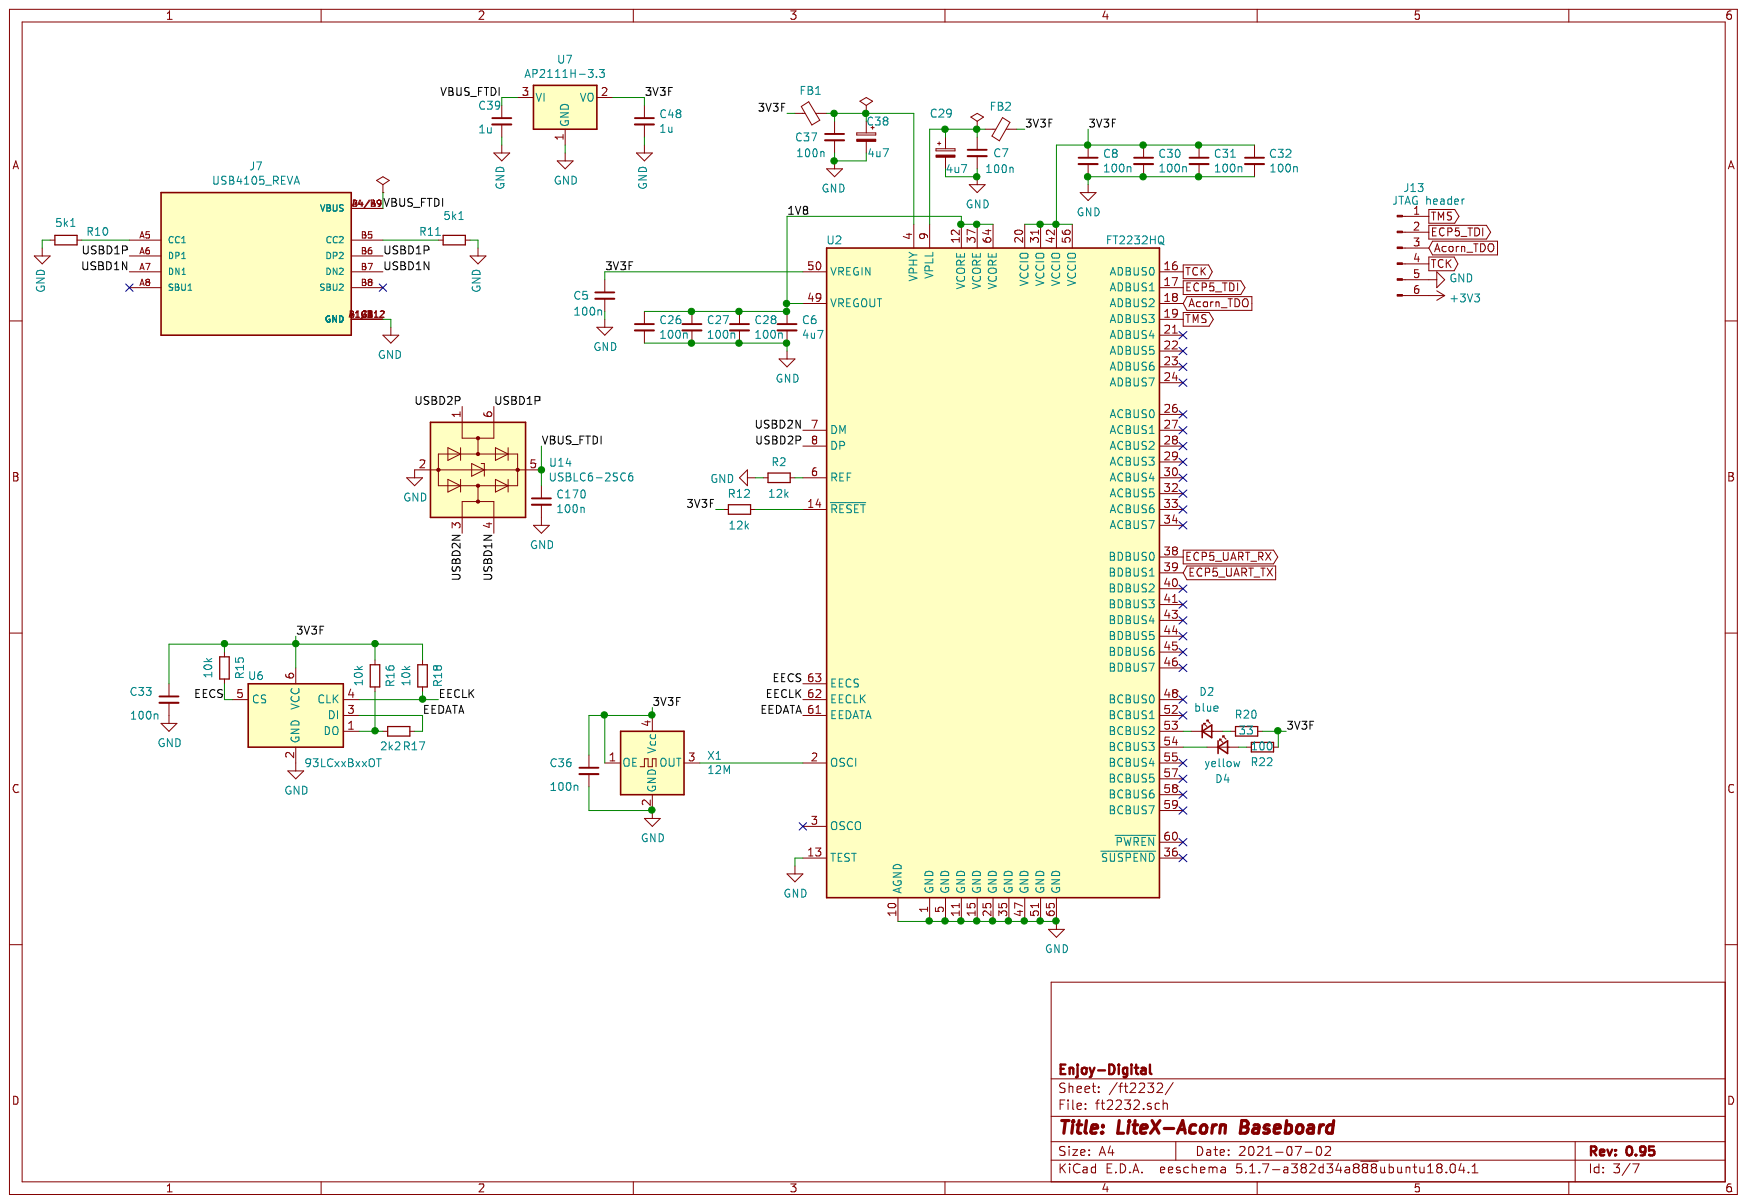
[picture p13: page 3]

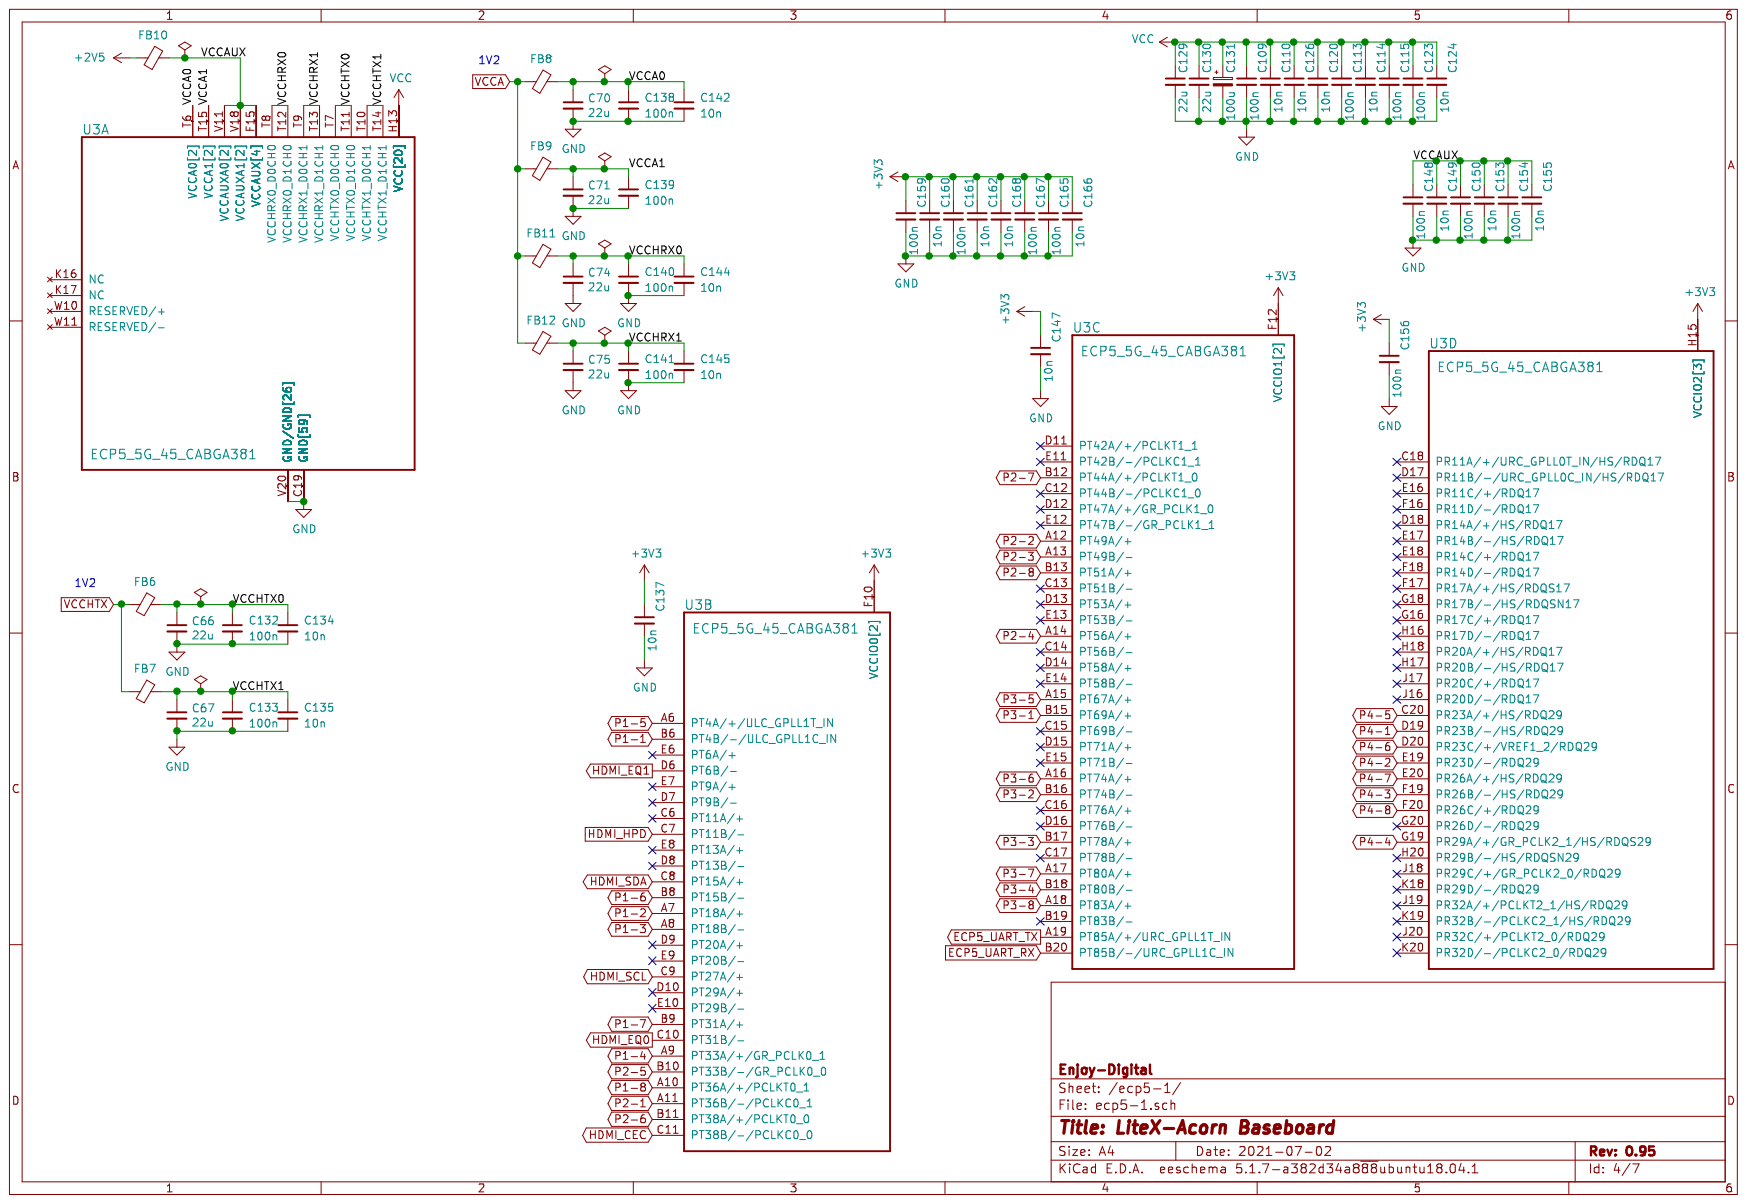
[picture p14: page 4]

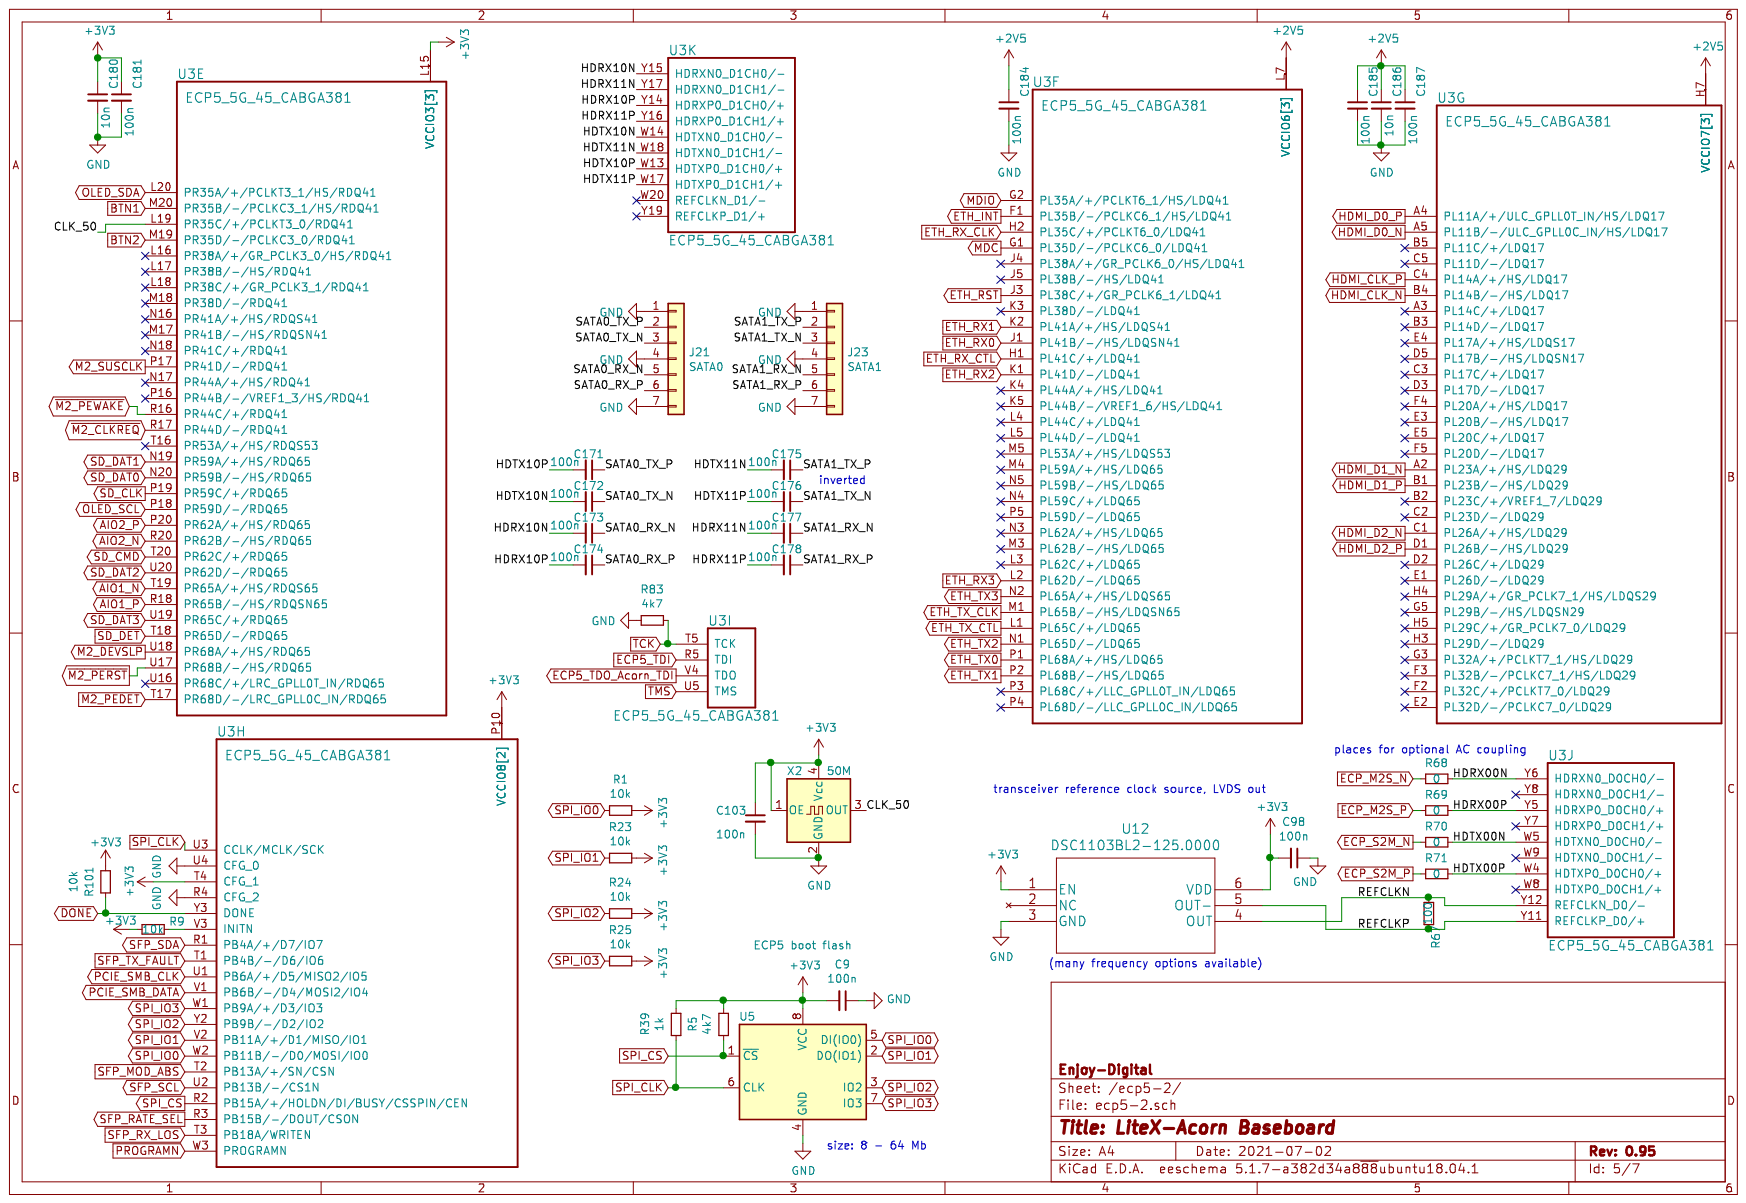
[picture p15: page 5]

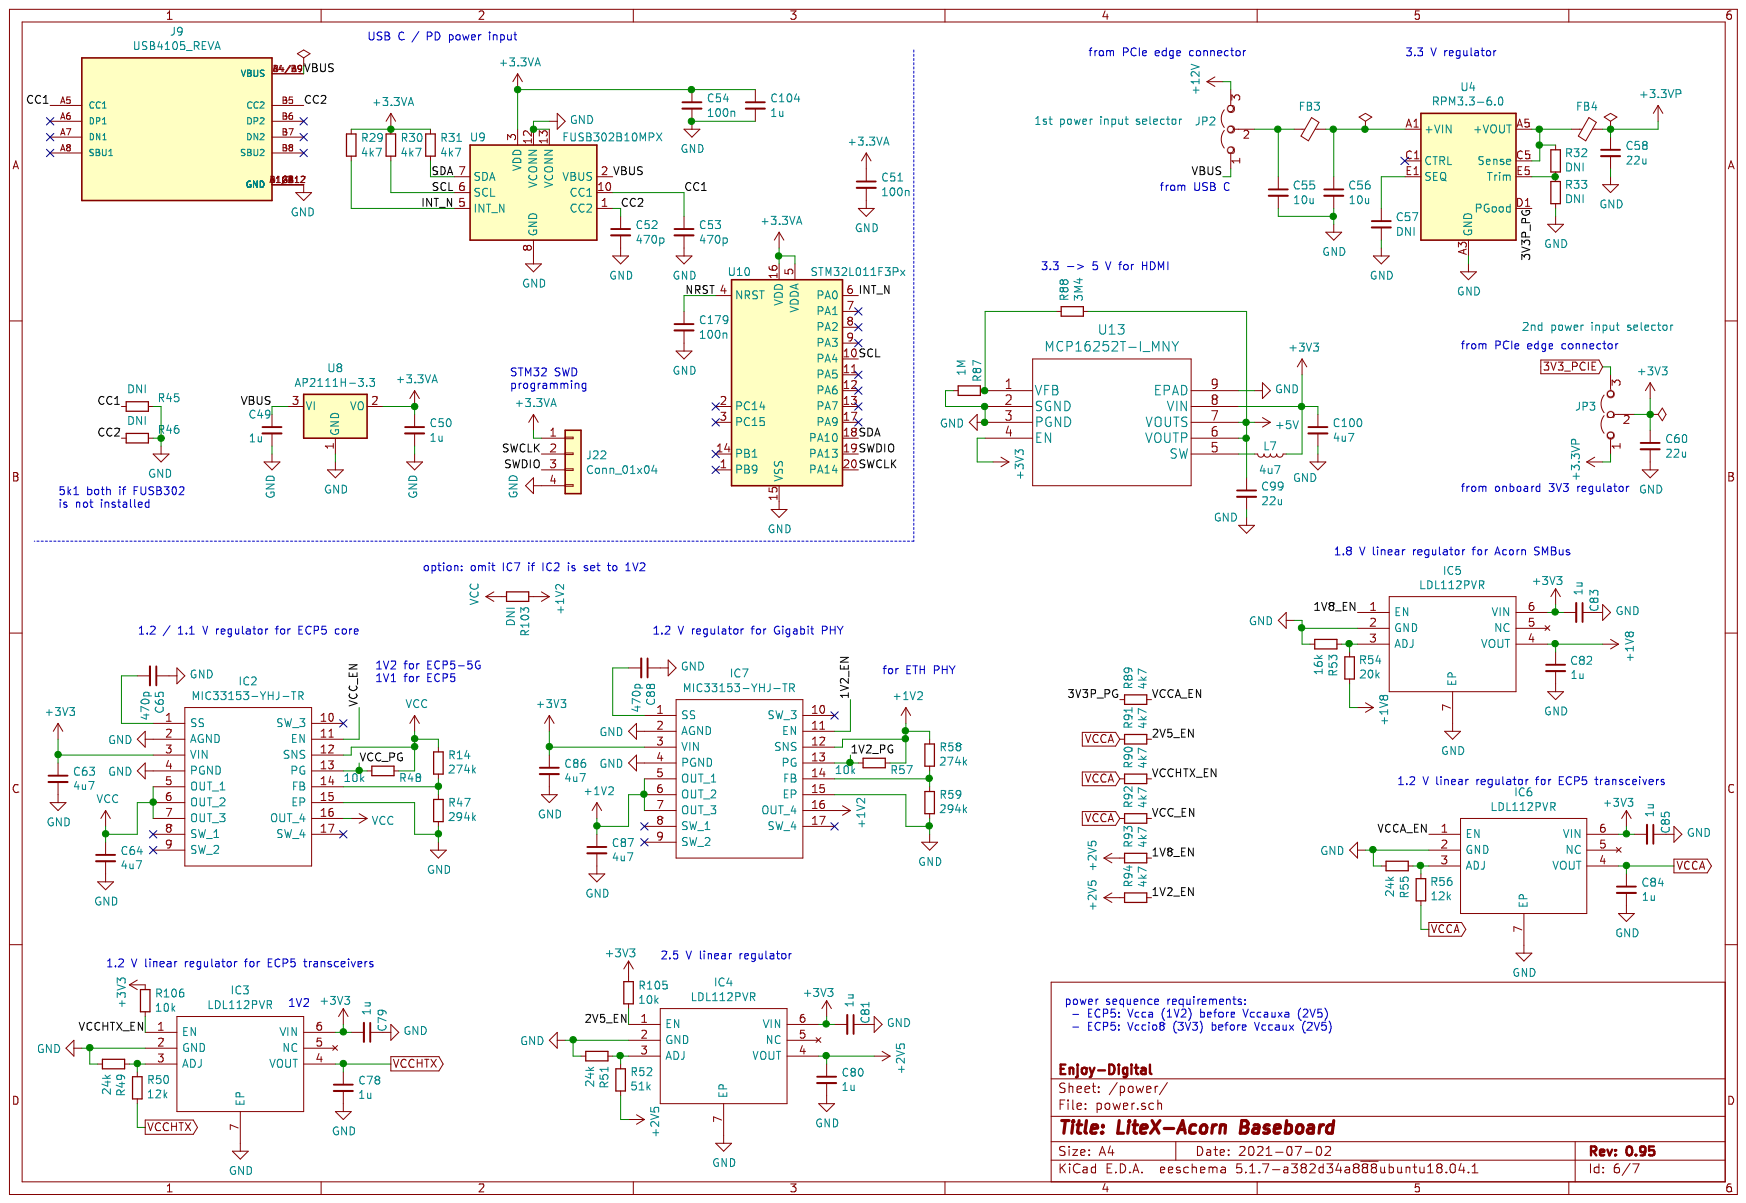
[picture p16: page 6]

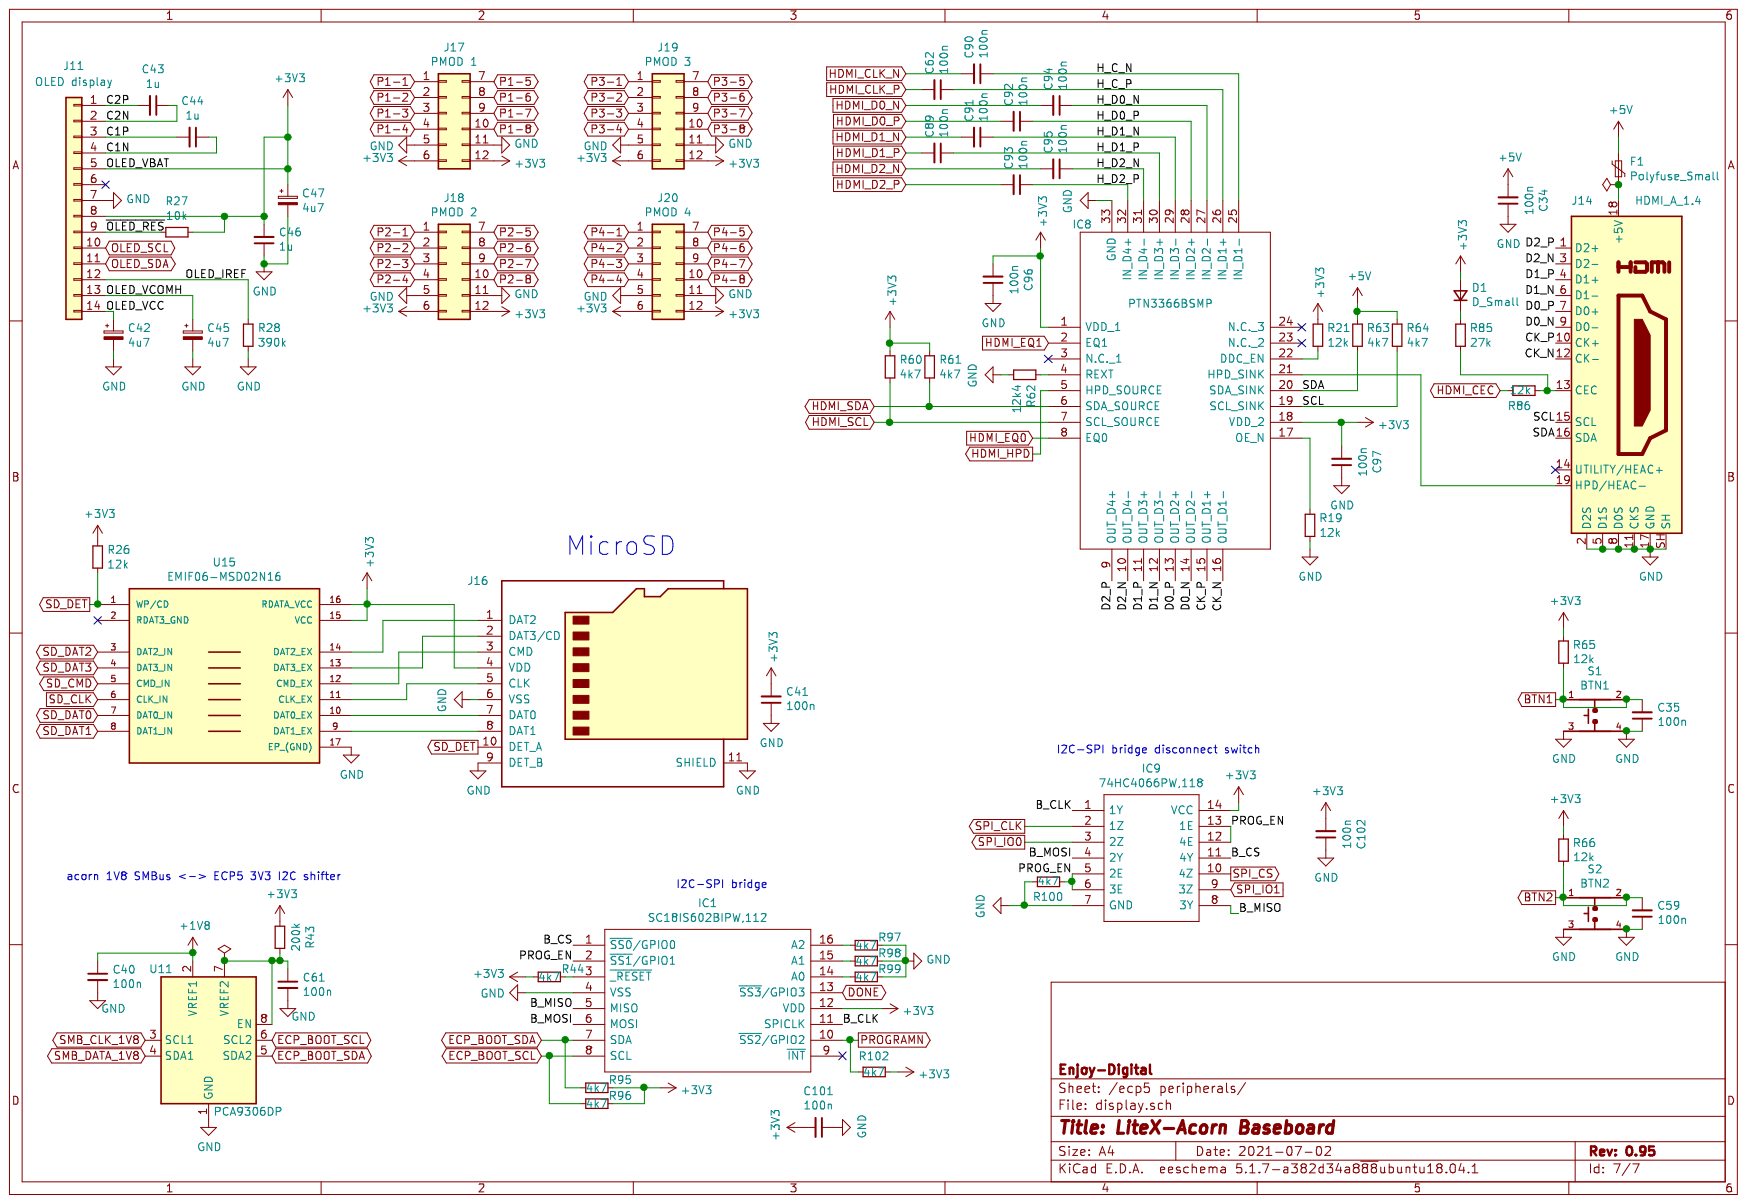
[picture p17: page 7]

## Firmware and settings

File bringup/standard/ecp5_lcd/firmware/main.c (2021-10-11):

// This file is Copyright (c) 2020 Florent Kermarrec <florent@enjoy-digital.fr>
// License: BSD

#include <stdio.h>
#include <stdlib.h>
#include <string.h>

#include <irq.h>
#include <libbase/uart.h>
#include <libbase/console.h>
#include <libbase/i2c.h>

#include <generated/csr.h>

/*-----------------------------------------------------------------------*/
/* Uart                                                                  */
/*-----------------------------------------------------------------------*/

static char *readstr(void)
{
	char c[2];
	static char s[64];
	static int ptr = 0;

	if(readchar_nonblock()) {
		c[0] = getchar();
		c[1] = 0;
		switch(c[0]) {
			case 0x7f:
			case 0x08:
				if(ptr > 0) {
					ptr--;
					fputs("\x08 \x08", stdout);
				}
				break;
			case 0x07:
				break;
			case '\r':
			case '\n':
				s[ptr] = 0x00;
				fputs("\n", stdout);
				ptr = 0;
				return s;
			default:
				if(ptr >= (sizeof(s) - 1))
					break;
				fputs(c, stdout);
				s[ptr] = c[0];
				ptr++;
				break;
		}
	}

	return NULL;
}

static char *get_token(char **str)
{
	char *c, *d;

	c = (char *)strchr(*str, ' ');
	if(c == NULL) {
		d = *str;
		*str = *str+strlen(*str);
		return d;
	}
	*c = 0;
	d = *str;
	*str = c+1;
	return d;
}

static void prompt(void)
{
	printf("\e[92;1mlitex-demo-app\e[0m> ");
}

/*-----------------------------------------------------------------------*/
/* Help                                                                  */
/*-----------------------------------------------------------------------*/

static void help(void)
{
	puts("\nLiteX lcd test app built "__DATE__" "__TIME__"\n");
	puts("Available commands:");
	puts("help               - Show this command");
	puts("reboot             - Reboot CPU");
	puts("lcd                - LCD test");
}

/*-----------------------------------------------------------------------*/
/* Commands                                                              */
/*-----------------------------------------------------------------------*/

static void reboot_cmd(void)
{
	ctrl_reset_write(1);
}

/* From https://github.com/uNetworking/SSD1306/blob/master/ssd1306_minimal.h */

unsigned char SSD1306_MINIMAL_framebuffer[1024];
#define SSD1306_MINIMAL_SLAVE_ADDR 0x3c

/* Transfers the entire framebuffer in 64 I2C data messages */
static void SSD1306_MINIMAL_transferFramebuffer(void) {
  unsigned char *p = SSD1306_MINIMAL_framebuffer;
  for (int i = 0; i < 64; i++) {
  		i2c_write(SSD1306_MINIMAL_SLAVE_ADDR, 0x40, p, 16);
  }
}

/* Horizontal addressing mode maps to linear framebuffer */
static void SSD1306_MINIMAL_setPixel(unsigned int x, unsigned int y) {
  x &= 0x7f;
  y &= 0x3f;
  SSD1306_MINIMAL_framebuffer[((y & 0xf8) << 4) + x] |= 1 << (y & 7);
}

const unsigned char lcd_init[] = {

	/* Enable charge pump regulator (RESET = ) */
	0x8d,
	0x14,
	/* Display On (RESET = ) */
	0xaf,
	/* Set Memory Addressing Mode to Horizontal Addressing Mode (RESET = Page Addressing Mode) */
	0x20,
	0x0,
	/* Reset Column Address (for horizontal addressing) */
	0x21,
	0,
	127,
	/* Reset Page Address (for horizontal addressing) */
	0x22,
	0,
	7
  };

static void lcd_cmd(void)
{
	int i;
	int x, y;

	/* LCD initialization */
	for (i = 0; i < sizeof(lcd_init); i++)
		i2c_write(SSD1306_MINIMAL_SLAVE_ADDR, 0x80, &lcd_init[i], 1);

	/* LCD test */

	/* Clear Framebuffer */
	for (int i = 0; i < 1024; i++) {
		SSD1306_MINIMAL_framebuffer[i] = 0;
	  }

	 for (x=0; x<64; x+=2) {
	 	for (y=0; y<16; y+=2) {
	  		SSD1306_MINIMAL_setPixel(x, y);
	  	}
	  }

	/* Transfer framebuffer to device */
	SSD1306_MINIMAL_transferFramebuffer();
}

/*-----------------------------------------------------------------------*/
/* Console service / Main                                                */
/*-----------------------------------------------------------------------*/

static void console_service(void)
{
	char *str;
	char *token;

	str = readstr();
	if(str == NULL) return;
	token = get_token(&str);
	if(strcmp(token, "help") == 0)
		help();
	else if(strcmp(token, "reboot") == 0)
		reboot_cmd();
	else if(strcmp(token, "lcd") == 0)
		lcd_cmd();
	prompt();
}

int main(void)
{
#ifdef CONFIG_CPU_HAS_INTERRUPT
	irq_setmask(0);
	irq_setie(1);
#endif
	uart_init();

	help();
	prompt();

	while(1) {
		console_service();
	}

	return 0;
}

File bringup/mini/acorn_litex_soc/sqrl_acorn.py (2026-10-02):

#!/usr/bin/env python3

#
# This file is part of LiteX-Boards.
#
# Copyright (c) 2020 Florent Kermarrec <florent@enjoy-digital.fr>
# SPDX-License-Identifier: BSD-2-Clause

# Build/Use ----------------------------------------------------------------------------------------
# Build/Load bitstream:
# ./sqrl_acorn.py --build --load
# litex_term /dev/ttyUSBX (X=2 if only the baseboard connected).

import os

from migen import *

from litex.gen import LiteXModule

import sqrl_acorn_platform as sqrl_acorn

from litex.soc.interconnect.csr import *
from litex.soc.integration.soc_core import *
from litex.soc.integration.builder import *

from litex.soc.cores.clock import *
from litex.soc.cores.led import LedChaser
from litex.soc.cores.xadc import S7SystemMonitor
from litex.soc.cores.dna  import S7DNA

from litedram.modules import MT41K512M16
from litedram.phy import s7ddrphy

from litepcie.phy.s7pciephy import S7PCIEPHY
from litepcie.software import generate_litepcie_software

# CRG ----------------------------------------------------------------------------------------------

class CRG(LiteXModule):
    def __init__(self, platform, sys_clk_freq):
        self.rst          = Signal()
        self.cd_sys       = ClockDomain()
        self.cd_sys4x     = ClockDomain()
        self.cd_sys4x_dqs = ClockDomain()
        self.cd_idelay    = ClockDomain()

        # Clk/Rst
        clk200 = platform.request("clk200")

        # PLL
        self.pll = pll = S7PLL()
        self.comb += pll.reset.eq(self.rst)
        pll.register_clkin(clk200, 200e6)
        pll.create_clkout(self.cd_sys,       sys_clk_freq)
        pll.create_clkout(self.cd_sys4x,     4*sys_clk_freq)
        pll.create_clkout(self.cd_sys4x_dqs, 4*sys_clk_freq, phase=90)
        pll.create_clkout(self.cd_idelay,    200e6)
        platform.add_false_path_constraints(self.cd_sys.clk, pll.clkin) # Ignore sys_clk to pll.clkin path created by SoC's rst.

        self.idelayctrl = S7IDELAYCTRL(self.cd_idelay)

# BaseSoC -----------------------------------------------------------------------------------------

class BaseSoC(SoCCore):
    def __init__(self, variant="cle-215+", sys_clk_freq=100e6,
        with_led_chaser = True,
        with_pcie       = False,
        with_sata       = False,
        **kwargs):
        platform = sqrl_acorn.Platform(variant=variant)

        # CRG --------------------------------------------------------------------------------------
        self.crg = CRG(platform, sys_clk_freq)

        # SoCCore ----------------------------------------------------------------------------------
        SoCCore.__init__(self, platform, sys_clk_freq, ident="LiteX SoC on Acorn CLE-101/215(+)", **kwargs)

        # XADC -------------------------------------------------------------------------------------
        self.xadc = S7SystemMonitor()

        # DNA --------------------------------------------------------------------------------------
        self.dna = S7DNA()
        self.dna.add_timing_constraints(platform, sys_clk_freq, self.crg.cd_sys.clk)

        # DDR3 SDRAM -------------------------------------------------------------------------------
        if not self.integrated_main_ram_size:
            self.ddrphy = s7ddrphy.A7DDRPHY(platform.request("ddram"),
                memtype          = "DDR3",
                nphases          = 4,
                sys_clk_freq     = sys_clk_freq,
                iodelay_clk_freq = 200e6)
            self.add_sdram("sdram",
                phy           = self.ddrphy,
                module        = MT41K512M16(sys_clk_freq, "1:4"),
                l2_cache_size = kwargs.get("l2_size", 8192)
            )

        # PCIe -------------------------------------------------------------------------------------
        if with_pcie:
            self.pcie_phy = S7PCIEPHY(platform, platform.request("pcie_x4"),
                data_width = 128,
                bar0_size  = 0x20000)
            self.add_pcie(phy=self.pcie_phy, ndmas=1, address_width=64)
            # FIXME: Apply it to all targets (integrate it in LitePCIe?).
            platform.add_period_constraint(self.crg.cd_sys.clk, 1e9/sys_clk_freq)
            platform.toolchain.pre_placement_commands.add("set_clock_groups -group [get_clocks {sys_clk}] -group [get_clocks userclk2] -asynchronous", sys_clk=self.crg.cd_sys.clk)
            platform.toolchain.pre_placement_commands.add("set_clock_groups -group [get_clocks {sys_clk}] -group [get_clocks clk_125mhz] -asynchronous", sys_clk=self.crg.cd_sys.clk)
            platform.toolchain.pre_placement_commands.add("set_clock_groups -group [get_clocks {sys_clk}] -group [get_clocks clk_250mhz] -asynchronous", sys_clk=self.crg.cd_sys.clk)
            platform.toolchain.pre_placement_commands.add("set_clock_groups -group [get_clocks clk_125mhz] -group [get_clocks clk_250mhz] -asynchronous")

            # ICAP (For FPGA reload over PCIe).
            from litex.soc.cores.icap import ICAP
            self.icap = ICAP()
            self.icap.add_reload()
            self.icap.add_timing_constraints(platform, sys_clk_freq, self.crg.cd_sys.clk)

            # Flash (For SPIFlash update over PCIe).
            from litex.soc.cores.gpio import GPIOOut
            from litex.soc.cores.spi_flash import S7SPIFlash
            self.flash_cs_n = GPIOOut(platform.request("flash_cs_n"))
            self.flash      = S7SPIFlash(platform.request("flash"), sys_clk_freq, 25e6)

        # SATA -------------------------------------------------------------------------------------
        if with_sata:
            from litex.build.generic_platform import Subsignal, Pins
            from litesata.phy import LiteSATAPHY

            # IOs
            _sata_io = [
                 # PCIe 2 SATA Custom Adapter (With PCIe Riser / SATA cable mod).
                ("pcie2sata", 0,
                    Subsignal("tx_p",  Pins("B6")),
                    Subsignal("tx_n",  Pins("A6")),
                    Subsignal("rx_p",  Pins("B10")),
                    Subsignal("rx_n",  Pins("A10")),
                ),
            ]
            platform.add_extension(_sata_io)

            # RefClk, Generate 150MHz from PLL.
            self.cd_sata_refclk = ClockDomain()
            self.crg.pll.create_clkout(self.cd_sata_refclk, 150e6)
            sata_refclk = ClockSignal("sata_refclk")
            platform.add_platform_command("set_property SEVERITY {{Warning}} [get_drc_checks REQP-49]")

            # PHY
            self.sata_phy = LiteSATAPHY(platform.device,
                refclk     = sata_refclk,
                pads       = platform.request("pcie2sata"),
                gen        = "gen1",
                clk_freq   = sys_clk_freq,
                data_width = 16)

            # Core
            self.add_sata(phy=self.sata_phy, mode="read+write")
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

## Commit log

2021-10-11 hardware: Add proto schematic.
2021-10-12 hardware: Add Acorn schematic.
    From https://github.com/RHSResearchLLC/NiteFury-and-LiteFury.
2021-10-13 acorn_pcie: Report link status on led.
2021-10-15 acorn_sfp_eth_1gbps: Add Acorn target from LiteX-Boards.
2021-10-15 hardware: Update schematic (was not up to date).
2021-10-23 add i2c test
    (cherry picked from commit 84f16e41b43e8b77fd04ddc3aa38e8ec46f783aa)
2022-02-20 cleanup and fix SFP 1G test
    [sqrl_acorn.py]
2022-03-07 acorn_ecp5_link: Add reset from button and default linerate of 2.5Gbps.
    [sqrl_acorn.py]
2022-11-10 hardware: Add acorn-baseboard-mini schematic.
2022-11-10 hardware: Fix acorn-baseboard-mini schematic (was only partial).
2022-11-10 bringup/mini: Add LiteX SoC test design (with CPU/DDR3/JTAG-UART).
2022-11-10 bringup/mini/acorn_litex_soc: Switch to regular UART instead of JTAG-UART.
    FTDI2232 UART is connected to M2 connector through CLK_REQ and SMB_ALERT_N signals.
2022-11-10 bringup/mini/acorn_serdes: Adapt and verify on PCIe connector.
2022-11-11 bringup/mini/acorn_serdes: Add SATA connector support.
2024-01-19 acorn_sfp_eth_1000basex: Switch sys_clk_freq to 156.25MHz.
2026-04-22 README: refresh for Mini commercialization.
    - Update Mini photo to current hardware (from webshop listing).
    - Add availability/pricing section with both product URLs.
    - Add Getting Started, Repository Layout (schematics, bring-ups), and
    Designs & Apps sections pointing to the wider LiteX ecosystem.
    - Update feature lists to match the shipping Mini (M.2, PicoEzMate,
    dual USB-C, FT2232H, onboard regulator).
    - Add DeepWiki and Buy-Hardware badges.
    - Bump copyright to 2026 and fix typos along the way.
2026-04-22 bringup: fix elaboration-time breakages caught by CI.
    - mini/acorn_sfp_eth_2500basex: A7_2500BASEX was moved into
    liteeth.phy.a7_1000basex; update import.
    - mini/acorn_pcie & standard/acorn_pcie: guard the user_led link-status
    wiring behind with_pcie so the script elaborates in the no-PCIe path.
    - standard/acorn_pcie: drop duplicate ident_version kwarg (already in
    soc_core_argdict, caused "multiple values" TypeError).
    - standard/acorn_sata: acorn platform was renamed to sqrl_acorn in
    litex-boards; update imports while keeping local "acorn" alias.
    All bring-up designs now elaborate cleanly in CI.
    [sqrl_acorn.py]
2026-04-22 Add flash.py production utility for Mini + Acorn CLE215(+).
    SQRL Acorn cards ship with SPI-flash write protection enabled, which
    previously required a two-tool dance (OpenOCD to write a dummy
    bitstream to lift protection, then openFPGALoader to flash the real
    image). openFPGALoader's --unprotect-flash covers the unlock step on
    its own, so this script collapses the whole procedure into a single
    Python CLI built around openFPGALoader only.
    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
2026-04-22 Bundle default production bitstream in prebuilt/.
    prebuilt/litex_acorn_baseboard_mini.bin is the bitstream pre-loaded on
    every board shipped from the webshop — a LiteX SoC with PCIe / Ethernet
    / SATA, good for a sanity check after unlocking the flash.
    flash.py now defaults to this local .bin (no network fetch), and the
    README documents the first-time-flash procedure accordingly.
2026-04-22 flash.py: route --unprotect through OpenOCD + BSCAN-SPI proxy.
    openFPGALoader's spi-over-jtag stub can't reach the flash on a
    factory-locked Acorn ("SPI Flash access failed: Read ID failed") even
    though SOJ itself loads and runs. The original pre-openFPGALoader
    litex-boards programmer handled this by writing a first bitstream
    through OpenOCD + a BSCAN-SPI proxy (bscan_spi_xc7a200t.bit), which
    resets the flash state and effectively unlocks the card. Replicate
    that flow here via litex.build.openocd.OpenOCD — the helper
    auto-downloads the .cfg and the proxy on first use.
    --unprotect now drives the OpenOCD path (slower, handles locked cards).
    --flash stays on openFPGALoader (fast, for already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
2026-04-22 flash.py: split --unprotect / --flash across openocd + openFPGALoader.
    Previous attempt had openocd write the full bitstream, which failed:
    the S25FL256S on the Acorn is a 32 MiB chip requiring 4-byte SPI
    addressing, and openocd's jtagspi driver only does 3-byte. Erases
    beyond sector 63 wrapped silently, verify reported contents diff.
    Better split matches what each tool is good at:
    - --unprotect: openocd + BSCAN-SPI proxy, minimum work — WREN then
    WRSR 0x00 to clear SRWD + BP[2:0]. No erase, no program.
    - --flash: openFPGALoader handles erase + program (including 4-byte
    addressing) once the block-protect bits are out of the way.
    Typical first-time bring-up: ./flash.py --unprotect --f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
2026-04-22 flash.py: send WREN/WRSR via raw irscan+drscan (openocd 0.11 compat).
    "jtagspi cmd" is an openocd 0.12+ command — on 0.11 it dispatches to
    "invalid command name 'jtagspi'". Replace it with raw irscan/drscan
    through the Xilinx USER1 register (IR 0x02), which is what the
    BSCAN-SPI proxy uses anyway and works on every openocd version that
    has jtagspi_init + drscan.
    openocd shifts LSB-first, SPI clocks MSB-first, so each byte sent on
    the wire is bit-reversed in the drscan value:
    WREN 0x06 -> drscan 8 0x60
    WRSR 0x01 + 0x00 -> drscan 16 0x0080
2026-04-22 flash.py: reset flash + clear CR on unprotect (handles QPI-stuck chips).
    On some boards the factory mining firmware leaves the S25FL256S with
    CR.QUAD set (flash in QPI mode) and/or 4-byte addressing enabled.
    Openocd's BSCAN-SPI proxy could still RDID because jtagspi uses the
    raw chain, but openFPGALoader's SOJ stub talks 1-wire SPI and gets
    no response ("Read ID failed"). Clearing only SR (1-byte WRSR) left
    CR untouched, so the chip stayed in QPI.
    Extended the unprotect sequence to:
    1. RESEN (0x66) + RESET (0x99) — software reset to power-on defaults
    (clears QPI, 4B mode, pending ops).
    2. WREN.
    3. WRSR with 2 data bytes: SR=0x00 + CR=0x00 — explicitly clears
    both registe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
2026-04-22 flash.py: route --flash through OpenOCD too (drop openFPGALoader).
    On some boards openFPGALoader's SOJ bitstream stalls at Done=0 after
    being loaded to SRAM — MMCM lock, EOS, INIT Complete all stay 0 and
    the SPI controller inside the stub never runs, so "Read ID failed"
    even when the flash is fully unprotected.
    OpenOCD's BSCAN-SPI proxy doesn't have that problem: BSCAN_USER works
    independent of the FPGA's full startup sequence, so the same board
    that openFPGALoader can't talk to is perfectly reachable through
    openocd. Since the Acorn's flash is only 32 MiB and our bitstreams
    fit in the first 16 MiB, we stay in 3-byte addressing and avoid the
    openocd jtagspi driver's 4-byte gap entirely.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
2026-04-22 flash.py: add SR/CR readback diagnostic + PPB erase in --unprotect.
    From reading openocd's jtagspi.c, jtagspi_protect() only sets an
    internal flag — it doesn't issue any SPI commands — so the driver's
    own "flash protect" op can't unlock a factory-locked chip. That means
    our WRSR sequence is the only thing that could be working, and the
    verify failures ("Was 0x00 instead of 0x22") say either WRSR isn't
    landing or there's a second protection layer still active.
    To find out which:
    - Read SR and RDCR before and after the unprotect sequence. openocd
    prints drscan TDO as hex; the register value comes back bit-reversed
    in the upper byte of the capture. If our WRSR worked, both read 0x00.
    -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
2026-04-22 flash.py: echo drscan TDO captures + Tcl reveal_reg helper.
    drscan returns the TDO capture as a Tcl *value*, it doesn't print it —
    previous diagnostic run printed the echo labels but nothing after
    them. Wrap each readback in a small Tcl proc that parses the 16-bit
    hex, extracts the upper byte (register value, bit-reversed because
    openocd shifts LSB-first) and prints both the decoded register and
    the raw drscan capture, e.g.:
    RDSR pre = 0x1c (raw drscan = 0x3800)
    Verified the Tcl helper parses + decodes correctly against openocd's
    Tcl interpreter with stubbed scans.
2026-04-22 flash.py: use openocd jtagspi cmd + openFPGALoader (both working).
    Verified end-to-end on the stuck board:
    - Raw irscan+drscan through the BSCAN-SPI proxy returned 0xffff for
    every read, on both openocd 0.11 and 0.12. The jtagspi driver's
    internal USER1+DR scan works (it probes the chip correctly), so
    something about two separate Tcl scans vs one queued pair doesn't
    reach the proxy. The fix is to use openocd's native `jtagspi cmd`
    subcommand (openocd 0.12+), which takes the same single-queue path.
    - `jtagspi cmd 0 1 0x05` (RDSR) and `jtagspi cmd 0 1 0x35` (RDCR) now
    return the actual register bytes. On the failing board SR was
    already 0x00 but CR = 0x02 — QUAD bit set — whi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
2026-04-22 flash.py: auto-detect openocd 0.12+ (LiteX build / oss-cad-suite).
    Stock Ubuntu 22.04 ships openocd 0.11, which lacks the 'jtagspi cmd'
    subcommand. Previously the script would fall over with
    "invalid command name \"jtagspi\"" on those systems, and relying on
    the user to set OPENOCD= by hand isn't friendly.
    Probe order:
    1. OPENOCD env var (explicit override — trust it unconditionally).
    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
2026-04-22 flash.py: re-enable QE bit after programming (Acorn boots SPIx4).
    The Acorn CLE-215+ configures in Master SPIx4 boot mode, which needs
    the flash's Configuration Register QE bit = 1 for the FPGA to fetch
    its bitstream on power-up. --unprotect deliberately clears QE (so
    openFPGALoader's 1-wire spi-over-jtag stub can read the chip), so
    if we don't put it back, the flash ends up correctly programmed but
    the board looks dead after power-cycle — nothing boots.
    openFPGALoader handles this cleanly: chaining --enable-quad after -f
    makes it set the QE bit as the last step of the same invocation. The
    output shows 'set_quad_bit: Done' which is what we want.
    Tested end-to-end on the stuck board:
    ./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
2026-04-22 flash.py: simplify --unprotect, let --enable-quad own CR.QUAD.
    Dropping the belt-and-suspenders CR clearing in --unprotect:
    - WRSR is now sent with 1 data byte (SR only), so CR is left untouched.
    - CR.QUAD handling is consolidated in --flash, where openFPGALoader's
    --enable-quad sets it to 1 as the last step — needed for the Acorn's
    Master SPIx4 boot anyway.
    End state is unchanged (SR=0x00, CR.QUAD=1) but the sequence no longer
    toggles QUAD 1→0→1, and boards where the factory left a non-default
    non-QUAD CR value keep whatever else might have been set (e.g. LC).
    README updated accordingly.
2026-09-27 Change rxn pin from C8 to A8 in sqrl_acorn.py
2026-10-02 bringup: Fix elaboration with current LiteX and extend CI coverage.
    - acorn_litex_soc: Use S7SystemMonitor/S7DNA (XADC/DNA were renamed).
    - acorn_sata: Remove add_csr calls (no longer needed/available).
    - acorn_i2c_ecp5: Fix VexRiscv import, missing os import, get_mem_data
    endianness argument and duplicated cpu_type.
    - CI: Also elaborate acorn_litex_soc --with-pcie, acorn_sata --with-analyzer
    and acorn_i2c_ecp5.
    [sqrl_acorn.py]
2026-10-02 mini: Auto-detect baseboard FTDI chip (FT2232H/FT4232H) for JTAG programming.
    LiteX-Acorn-Baseboard-Mini revisions use either a FT2232H or a FT4232H.
    Detect it from its USB VID:PID (similar to litex-boards' sqrl_acorn platform)
    to select the OpenOCD config and openFPGALoader cable, instead of hardcoding
    ft4232.
    - mini platforms: Add detect_ftdi_chip() and use it in create_programmer().
    - flash.py: Auto-detect chip, add --ftdi-chip override.
    - README: Mention both FTDI chips.
    Fixes #18.
    [sqrl_acorn_platform.py]
2026-10-02 mini: Add Digilent HS2 (FT232H) JTAG cable support.
    Allow programming/flashing the Acorn through an external Digilent HS2 cable
    connected to its JTAG header (similar to litex-boards' sqrl_acorn platform):
    - flash.py: Detect HS2 (0403:6014), use openocd_xc7_ft232.cfg for --unprotect
    and openFPGALoader digilent_hs2 cable for --flash (--ftdi-chip=ft232 to force).
    - mini platforms: Also detect HS2 in create_programmer().
    Fixes #19.
    [sqrl_acorn_platform.py]
2026-10-02 mini/acorn_pcie: Document PCIe enumeration (reboot/rescan) and flashing.
    The host only enumerates PCIe devices at boot, so a bitstream loaded over JTAG
    while the host is running is not directly visible in lspci. Document how to
    get it enumerated (warm reboot with --load, power-cycle with --flash, or PCIe
    rescan), the lspci vendor/device IDs and the LEDs meaning.
    See #20.
2026-10-02 hardware: Add Mini variant PCB top render and 3D model (STEP).
    Generated with KiCad 9 (kicad-cli) from the Mini variant KiCad design
    (v2_simplified). Top render makes connectors/jumpers references easier to
    read. M.2/SFP/SATA/USB-C connector 3D models are not included in the STEP.
    Fixes #21.
    [acorn-baseboard-mini.step]
2026-10-02 hardware: Update Mini variant 3D model/renders with all components modeled.
    Add 3D models for the components that were missing in the STEP/renders:
    - J7/J9 USB-C, J5 SATA, J2 M.2, J3/J8 SFP connectors/cages: LCSC/EasyEDA
    models (from BOM LCSC part numbers), aligned on footprints pads.
    - J6/J10 PicoEZmate: Molex 78171-5006 model.
    - U4 RECOM RPM3.3-6.0 and U9 FUSB302: simplified models (datasheet dimensions).
    - X1: KiCad 3225 crystal model (same package).
    Also add a 3D view render.
    [acorn-baseboard-mini.step]
2026-10-02 hardware: Add Mini variant connectors/jumpers reference (pinouts, power and SFP I2C jumpers).
2026-10-04 Update README with LED animation instructions
    Added instructions for LED animation confirmation after running the script.

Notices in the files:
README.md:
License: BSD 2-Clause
